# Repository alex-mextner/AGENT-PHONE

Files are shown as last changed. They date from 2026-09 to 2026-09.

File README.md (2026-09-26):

# AGENT-PHONE

**AGENT** is a wrist-worn personal computer built around a wide landscape display, [Agent OS](https://agentos-bible.vercel.app/), and keyboardless interaction. It is intentionally neither a miniature phone nor a conventional smartwatch. **AGENT-PHONE** is the public hardware repository name.

Working naming:
- **AGENT** — product / hardware family;
- **[Passport / Sapio State](https://github.com/alex-mextner/sapio-state)** — portable identity and residency research related to the device;
- **Screen** — descriptive name for the primary wrist display;
- **[Telekinesis](docs/input-research.md)** — multimodal screen-off input system;
- **[Agent Ring](docs/ring-and-spatial-input.md)** — tactile and spatial input accessory;
- **[Agent Camera](docs/camera-strategy.md)** — detachable photography module;
- **Agent Glasses** — optional gaze, spatial-context, and low-duty-cycle display accessory described across the companion-device research.

The product explores a simple premise: a personal computer should not need to occupy a hand, pocket or bag. AGENT stays on the wrist, keeps its display dark whenever possible, and hands heavy visual work to a nearby TV, monitor or optional glasses display.

## Product thesis

- One uninterrupted wide landscape OLED, visually around two Apple Watch Ultra faces side by side.
- Nearly borderless left/right edges.
- A very thin hidden tilt carrier so the wrist can rest naturally while the display faces the user.
- A detachable compute/display module with only a short-duration reserve battery.
- Most battery mass lives in the cuff/base and two curved battery plates integrated into the sides of the open cuff.
- An optional **external endurance battery** can move much more energy to the torso (underarm or lower back) through a flat clothing-integrated cable.
- Base model uses a wraparound cuff rather than a conventional buckle; Dive variant can use a secure clasp.
- No rigid battery brick under the wrist.
- eSIM only; no physical SIM.
- No games by design. Video and long-form visual work should prefer a larger nearby display.
- Optional glasses provide gaze, spatial context and a low-duty-cycle display; paired bone-conduction/private audio can read results back without lighting the wrist.
- Optional ring(s) provide tactile, spatial and eyes-free controls.
- A detachable camera tile handles deliberate photography better than pointing the whole wrist at a subject.
- Nearby displays are first-class outputs: TV/monitor, glasses and **car HUD** can receive the current navigation, media or task context instead of forcing it onto the wrist.

## Telekinesis input

**[Telekinesis](docs/input-research.md)** combines wrist sEMG, IMU, optical sensing, deliberate silent articulation, gaze, ring gestures and voice dictation.

The goal is not "mind reading." Silent speech is an intentional input mode. The system learns each user's deliberate subvocal articulation and only records it while the input mode is explicitly armed.

Screen-off composition is a core power and attention feature: the OLED can remain black while subtle haptics indicate input state, and private TTS can read the draft back for correction.

## Agent OS

AGENT is hardware for [Agent OS](https://agentos-bible.vercel.app/) ([source](https://github.com/alex-mextner/AgentOS)), an app-last, local-first, agent-native operating-system project.

Instead of shrinking phone apps onto a small display, AGENT presents task- and entity-specific views: a person, event, product, room, delivery, research task or photo can become the current interface.

See [AGENT hardware × Agent OS](docs/agent-os.md).

## Research and engineering documents

- [Product specification](SPEC.md)
- [Hardware architecture](docs/hardware-architecture.md)
- [Prototype BOM and sourcing](docs/bom.md)
- [Product and distribution strategy](docs/product-strategy.md)
- [Critical phone-failure scenarios](docs/critical-scenarios.md)
- [Deep research: keyboardless input](docs/input-research.md)
- [Ring and spatial input](docs/ring-and-spatial-input.md)
- [Camera strategy](docs/camera-strategy.md)
- [Display, silicon and connectivity](docs/display-and-connectivity.md)
- [Agent OS integration](docs/agent-os.md)
- [Visual references and design lessons](docs/references.md)
- [Naming notes](docs/naming.md)
- [Blender render pipeline](blender/README.md)

## Prototype strategy

The first physical builds deliberately separate ergonomic proof from full electronics.

1. **P0 ergonomic cuff** — PETG/TPU, real long OLED, batteries/weights in correct places, compact tilt/detach mechanism.
2. **P0 Telekinesis** — wrist sEMG/IMU + screen-off state machine, compute may remain off-body.
3. **P0 ring** — BLE/IMU/capacitive/squeeze DIY ring.
4. **P1 functional wrist** — embedded Linux/Agent OS services, camera tile, real power domains.
5. **P2 custom electronics** — wearable SoC, custom PCB/FPC, curved batteries and production-intent display.

This keeps an oversized development board from dictating the industrial design.

## Distribution hypothesis

The base AGENT device is intended to be distributed free to a limited waitlist/residency cohort. Revenue is explored through optional extensions, specialist accessories, commercial integrations and services rather than mandatory hardware margin.

This is a product hypothesis, not a finalized business model.

## Concept status

This repository is a research and industrial-design prototype. Dimensions, battery capacity, sensing accuracy, pricing and supplier availability are engineering targets or snapshots, not production claims.

## Concept renders

The [concept-render gallery](renders/) shows the device on-wrist, its tilt/detach mechanics, and representative interfaces. Current written specs remain the authority for dimensions and behavior while the physical prototype evolves.

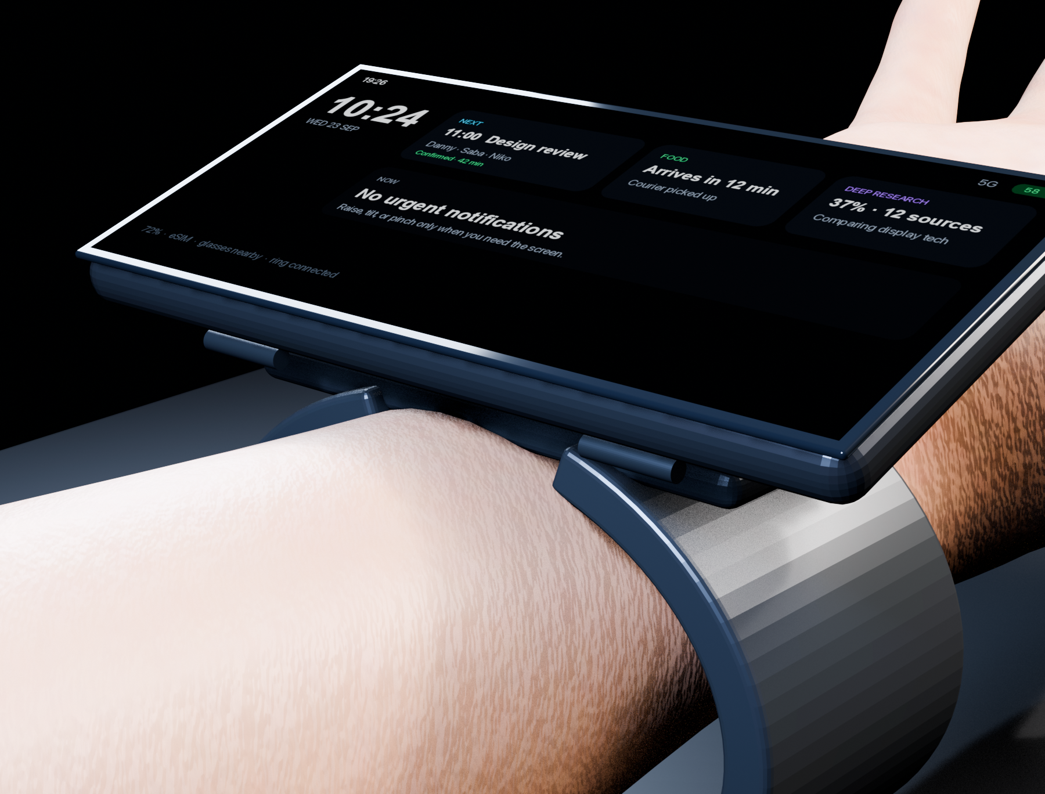
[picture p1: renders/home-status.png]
AGENT-PHONE home/status on wrist


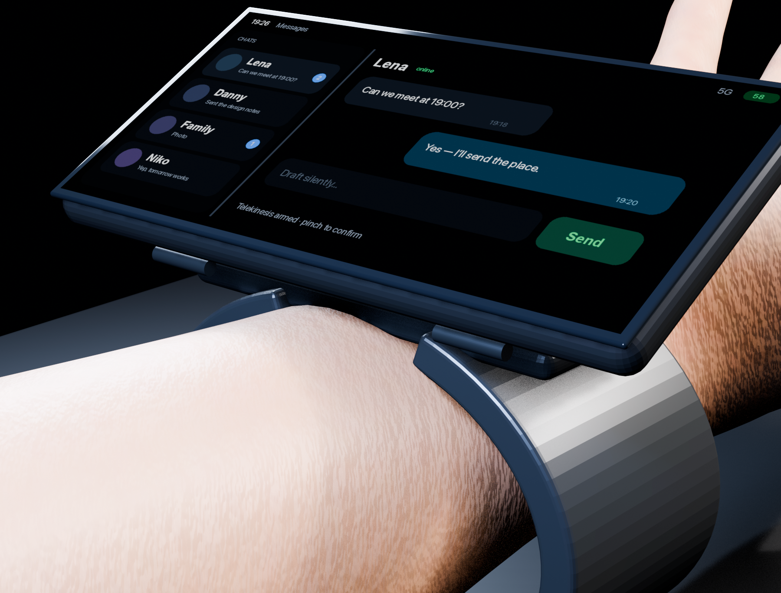
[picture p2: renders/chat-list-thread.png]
AGENT-PHONE chat list + thread


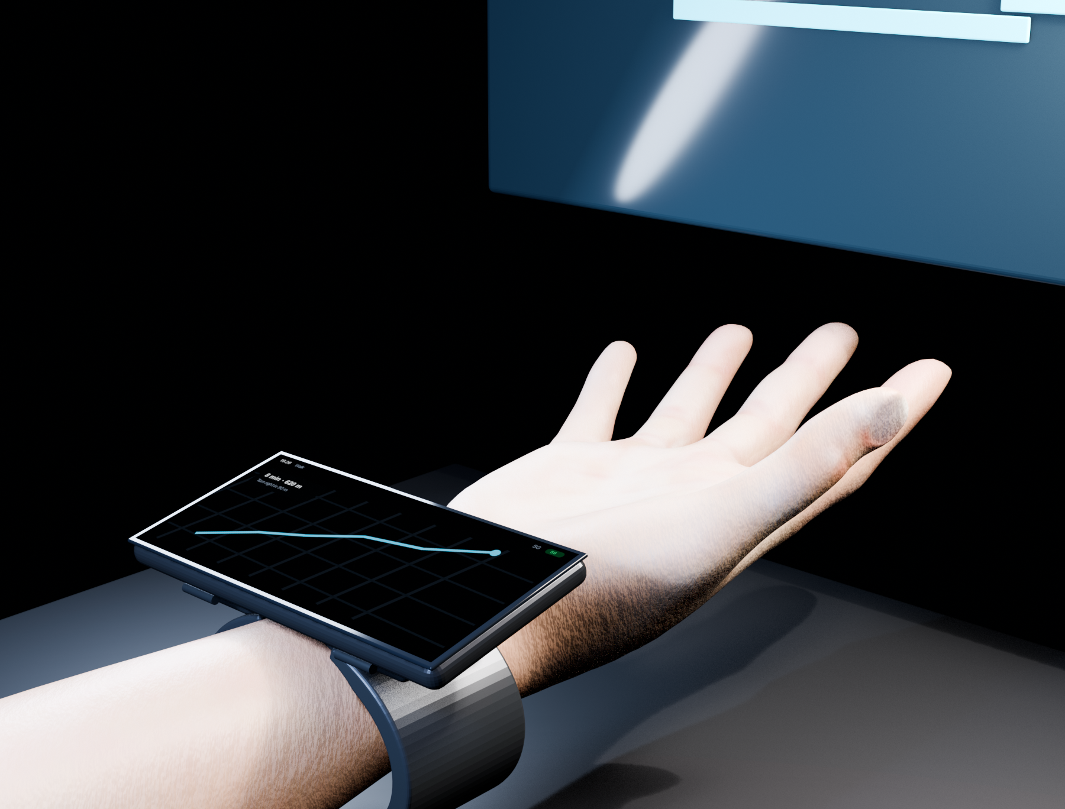
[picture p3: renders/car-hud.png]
AGENT-PHONE car HUD handoff


See [the full render set](renders/README.md).

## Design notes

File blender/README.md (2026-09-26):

# Render pipeline

Requires Blender 5.x and Python 3 with Pillow for UI texture generation.

## Generate UI textures

```bash
python3 blender/generate_ui.py
```

## Fetch the licensed human asset

```bash
python3 blender/fetch_human_asset.py
```

MakeHuman graphical assets are cached under `assets/human/cache/` and are not committed. Source/license details live in `assets/human/README.md`.

## Render concept views

```bash
/Applications/Blender.app/Contents/MacOS/Blender --background --python blender/screen_concept.py
```

Use `-- --scene car-hud`, `-- --scene ring-spatial`, or another scene name for one render. Add `-- --preview` for the lower-resolution preview path.

The current source checkpoint is `renders/agent-phone-concept.blend`.

## Design intent encoded by the model

- 94 × 45 mm module: approximately two Watch Ultra-sized faces side by side;
- long display axis **across the wrist**;
- edge-to-edge glass with a subordinate structural rim;
- two curved battery plates integrated into the open cuff;
- rigid cuff stops before the underside desk-contact zone;
- recessed tilt mechanism with 0° / 30° / 55° validation states;
- detachable display/compute module with a small reserve cell;
- licensed MakeHuman wrist/hand asset for lifestyle scenes;
- companion contexts for TV handoff, ring, glasses/private audio, camera tile, external battery, Dive clasp, desk/laptop and car HUD;
- every public UI state is rendered on the worn device.

This remains an industrial-design massing model, not production CAD.

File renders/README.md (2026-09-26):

# Concept renders

These images document the current AGENT-PHONE industrial-design and interaction concept. Implementation details for generating them live in [`blender/`](../blender/README.md).

## Scale and mechanics

| View | What it proves |
| --- | --- |
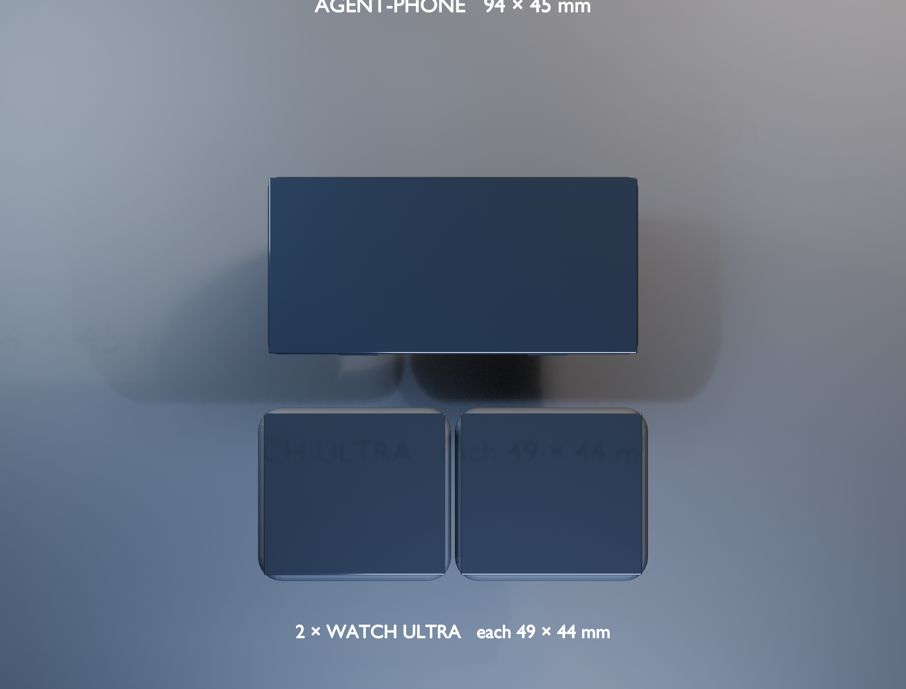
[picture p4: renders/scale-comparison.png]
Scale comparison
|  | 94 × 45 mm AGENT-PHONE compared directly with two 49 × 44 mm Watch Ultra-sized references |
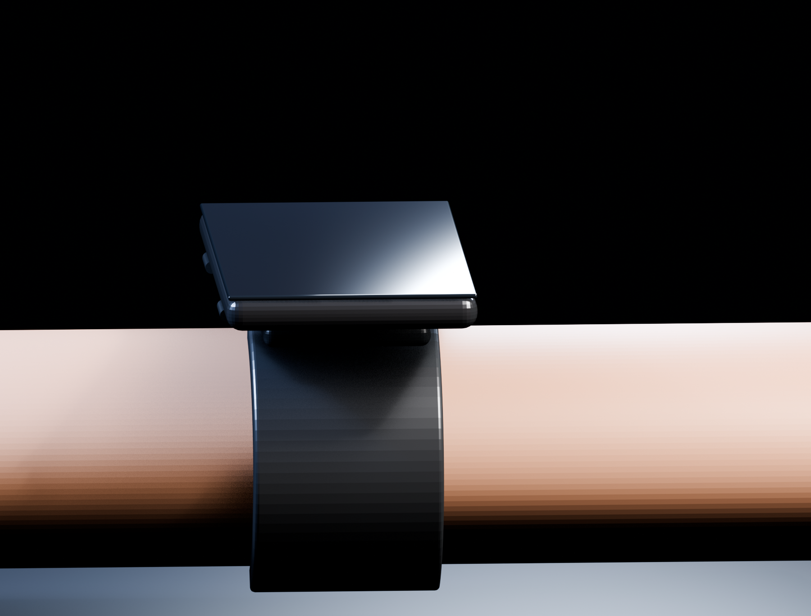
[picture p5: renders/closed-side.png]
Closed side
|  | closed thin module over the open cuff |
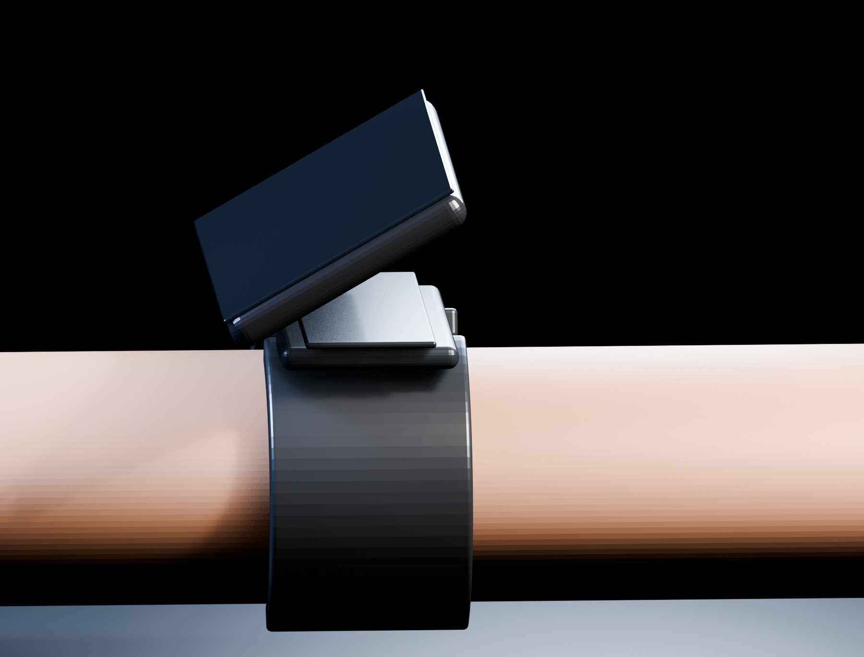
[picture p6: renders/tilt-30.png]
Tilt 30
|  | first comfortable reading angle while the arm rests |
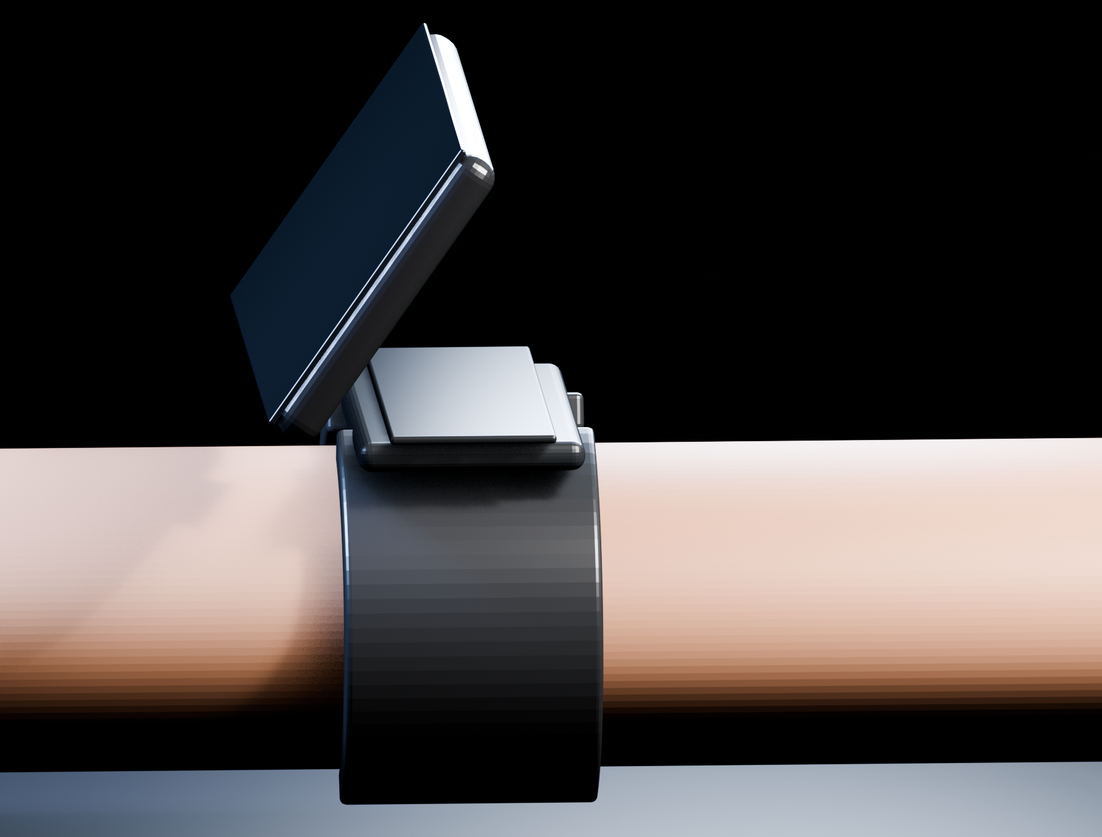
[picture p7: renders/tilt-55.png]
Tilt 55
|  | high tilt with the hinge still recessed |
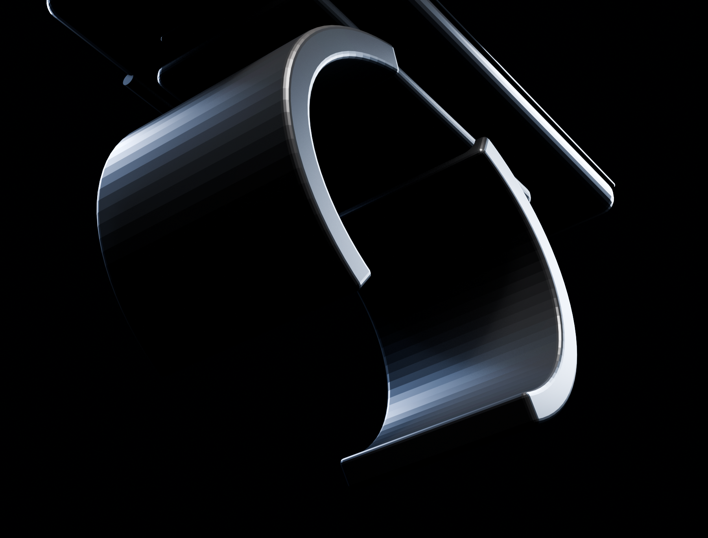
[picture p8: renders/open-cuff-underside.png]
Open cuff underside
|  | rigid battery plates stop before the desk-contact underside of the wrist |
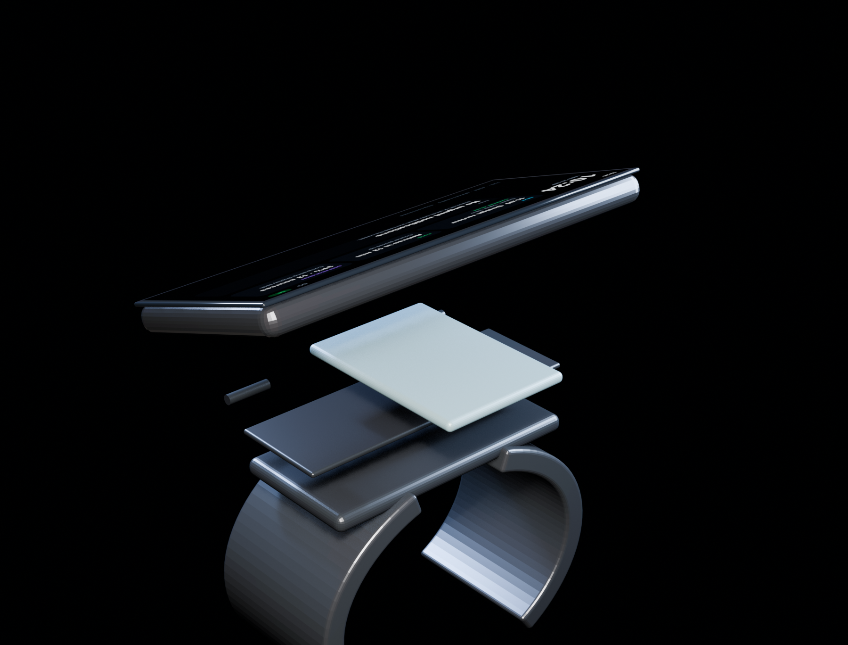
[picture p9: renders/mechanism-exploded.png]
Exploded mechanism
|  | display/compute module, thin carrier, reserve cell, contacts and cuff separated |
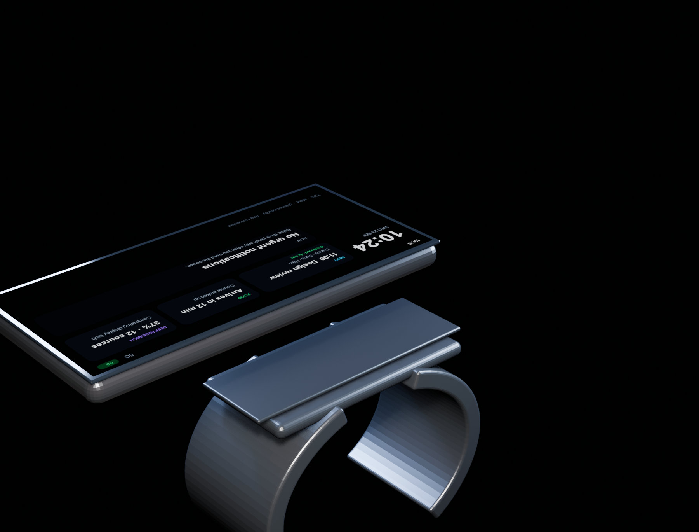
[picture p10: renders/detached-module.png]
Detached module
|  | removable display/compute module remains a coherent thin object |

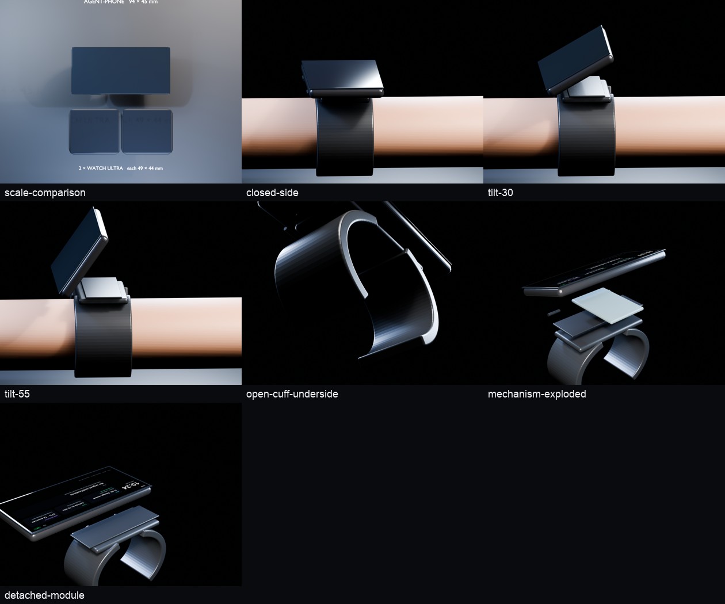
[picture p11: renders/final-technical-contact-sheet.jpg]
Technical contact sheet


## On-wrist scenarios

| View | Scenario |
| --- | --- |
| Home/status | next calendar event, food delivery and long-running AI research |
| Chat | chat list on the left, active thread on the right |
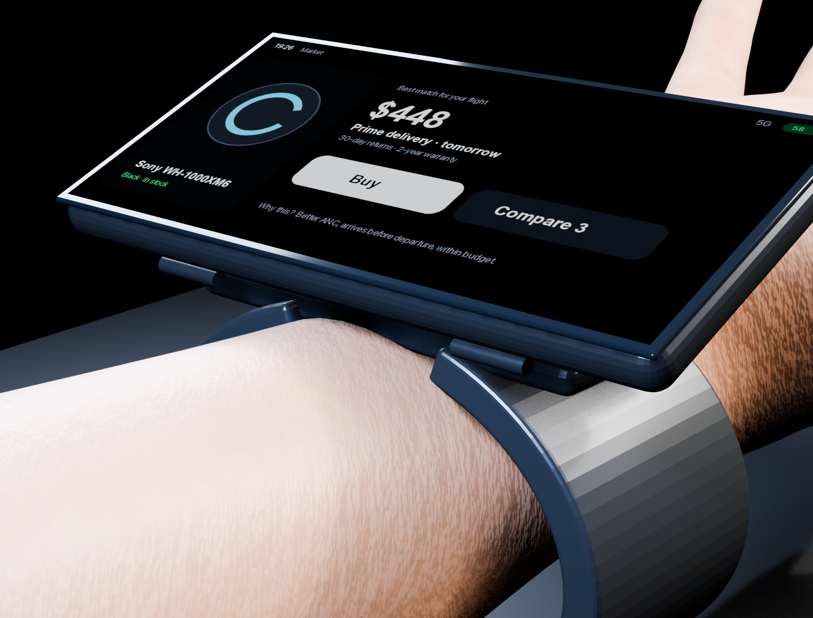
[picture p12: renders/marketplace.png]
Marketplace
|  | product decision and purchase without a phone-sized portrait app |
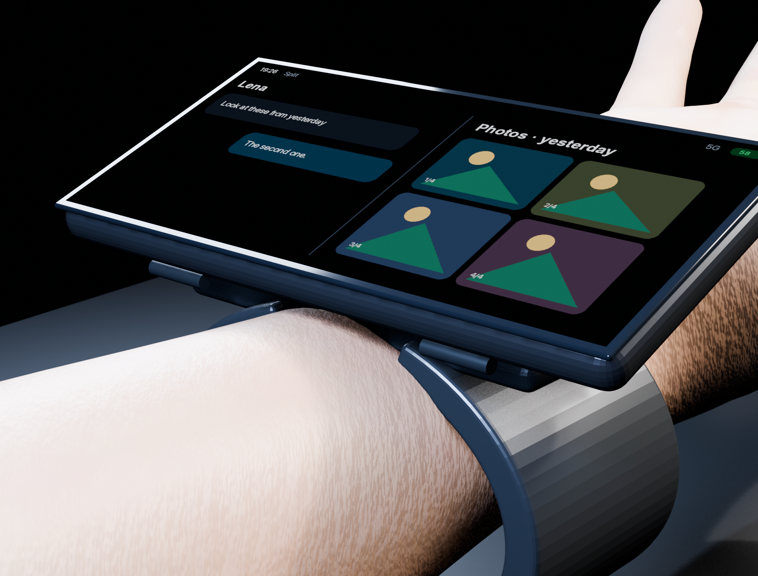
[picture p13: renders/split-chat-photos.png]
Split
|  | chat + photos on one wide surface |
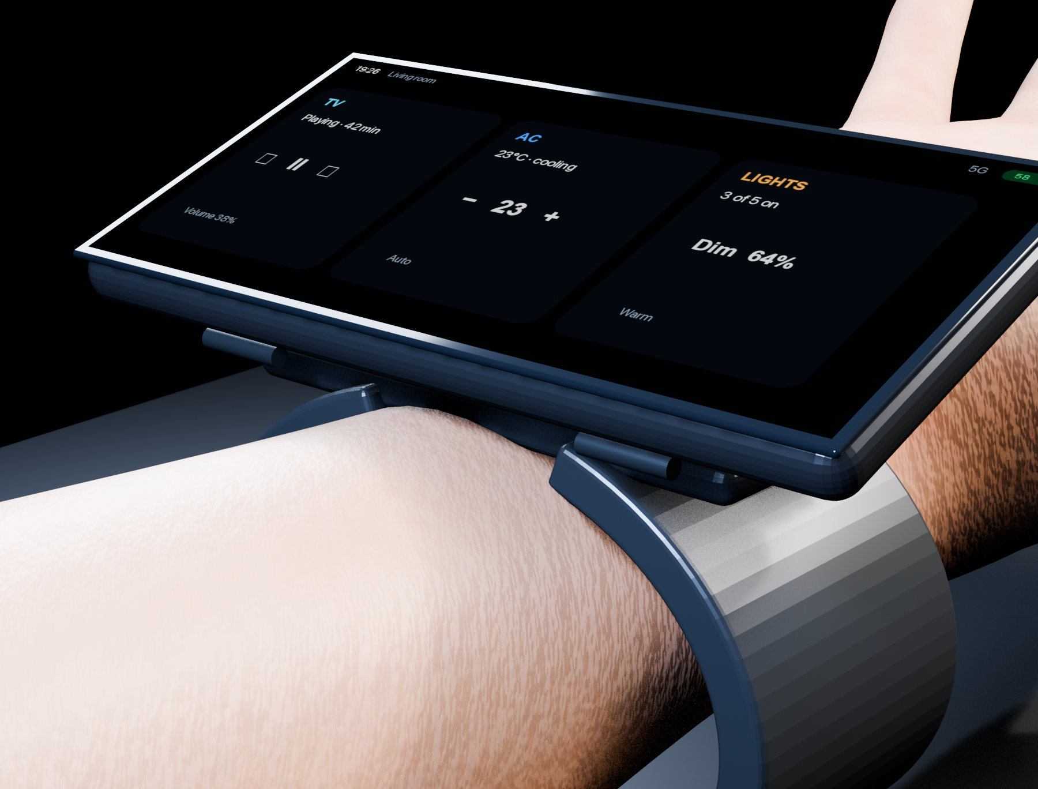
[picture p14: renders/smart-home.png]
Smart home
|  | TV / AC / lighting control |
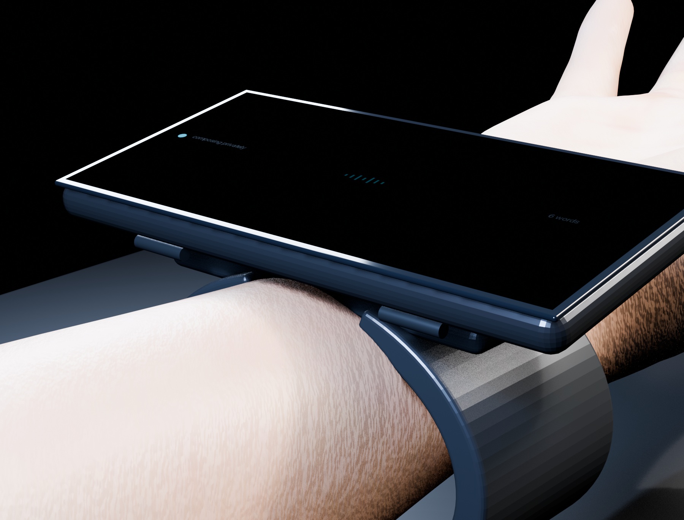
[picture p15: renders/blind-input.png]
Blind input
|  | almost-black screen during private Telekinesis composition |
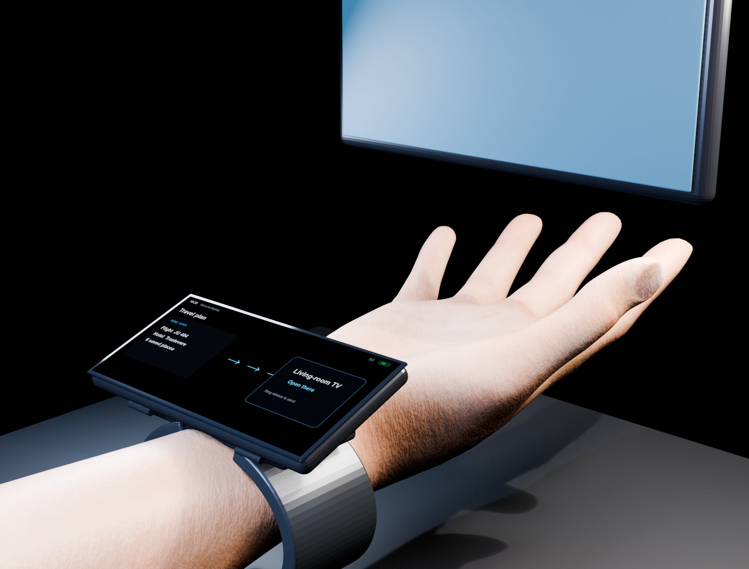
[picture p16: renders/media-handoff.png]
Media handoff
|  | move the current entity to a nearby TV |
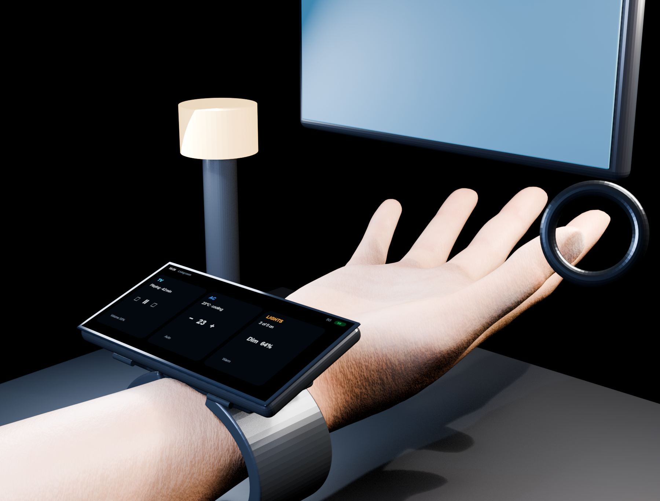
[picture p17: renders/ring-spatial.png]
Ring spatial
|  | ring + room context for spatial device control |
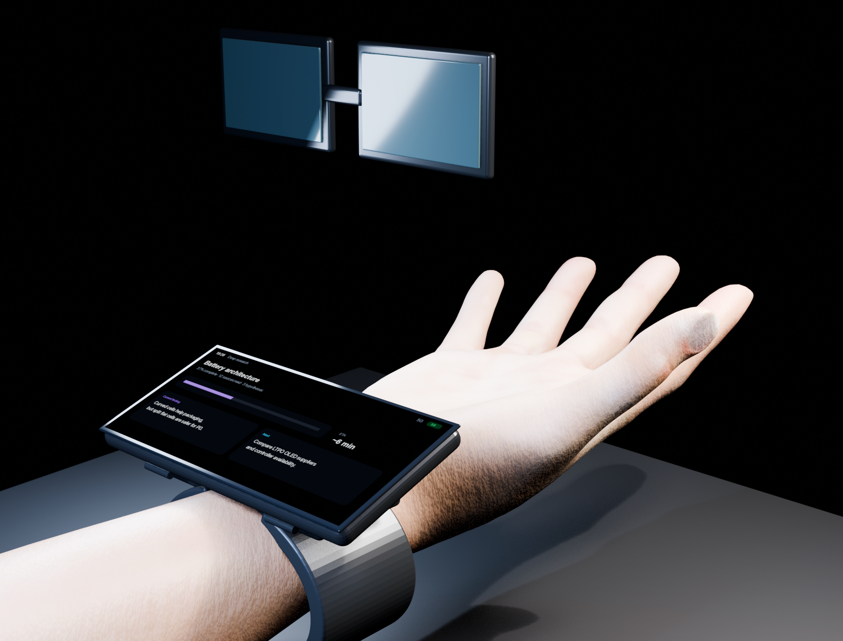
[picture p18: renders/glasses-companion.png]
Glasses companion
|  | glasses, gaze/spatial context and private audio companion |
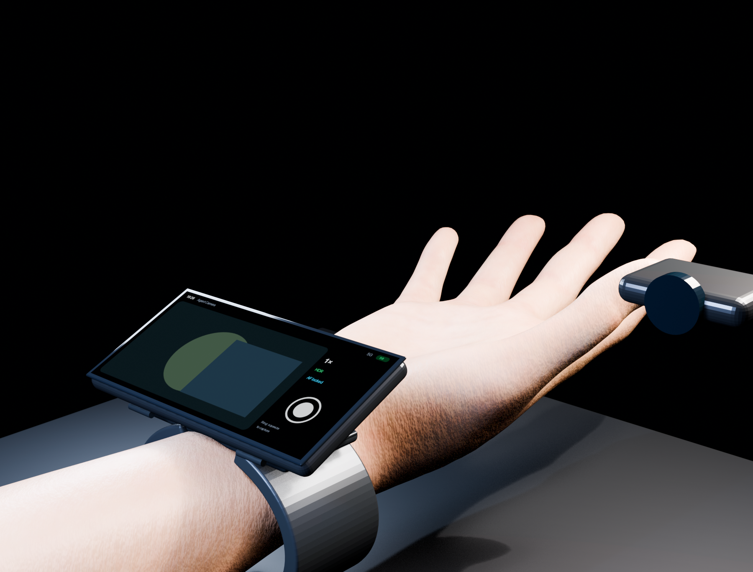
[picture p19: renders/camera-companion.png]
Camera companion
|  | detachable camera tile with the wrist as controller/viewfinder |
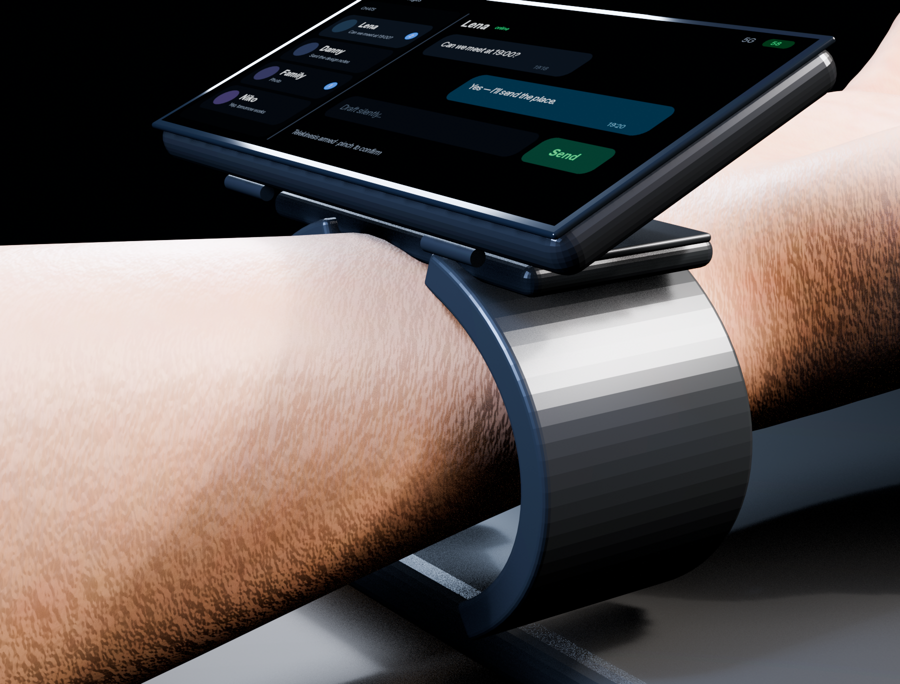
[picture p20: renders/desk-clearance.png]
Desk clearance
|  | open cuff leaves the underside usable against a desk/laptop |
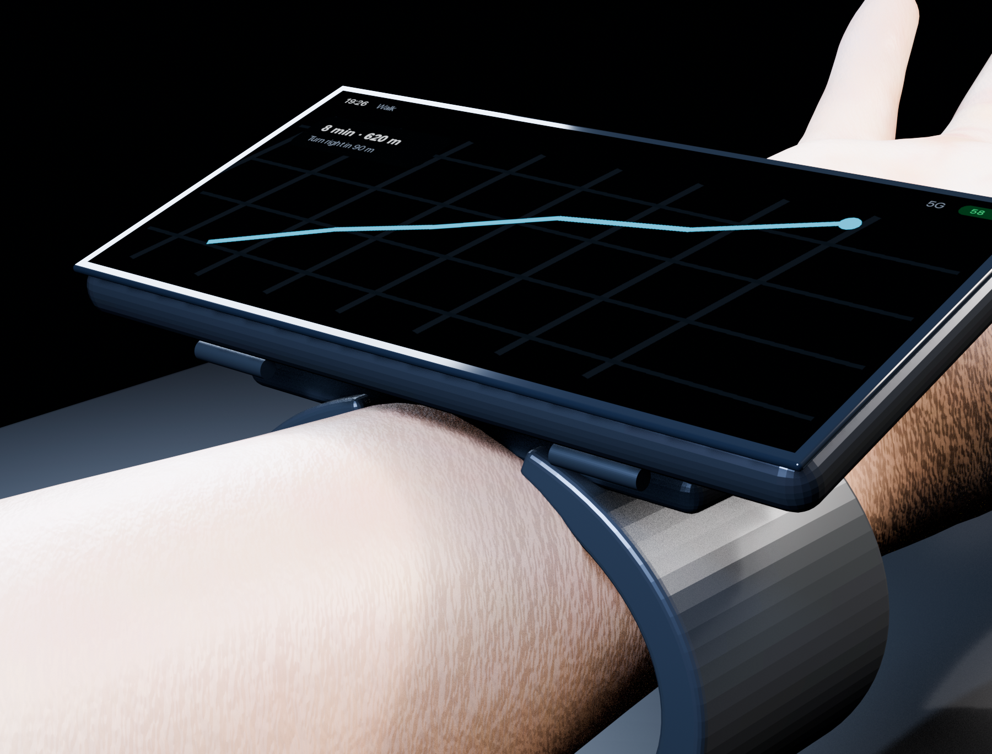
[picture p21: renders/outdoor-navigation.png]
Outdoor navigation
|  | quick glance navigation |
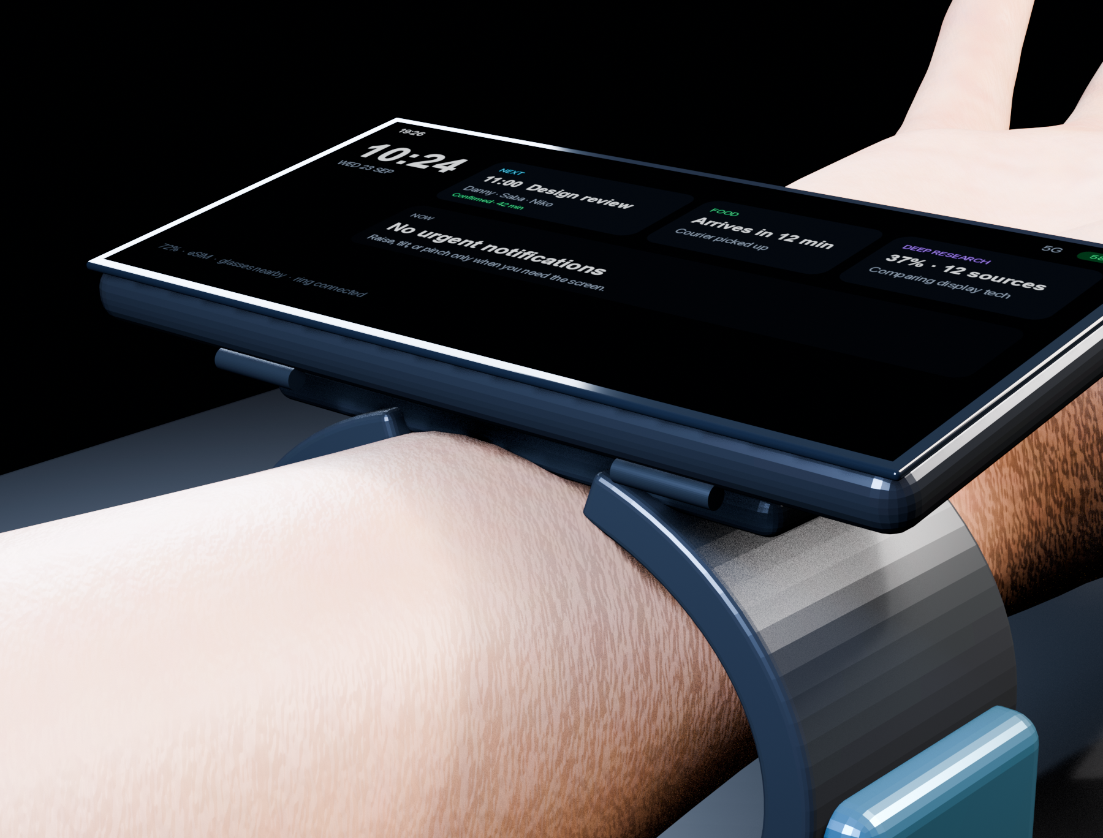
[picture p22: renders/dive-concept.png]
Dive concept
|  | secure-clasp variant for water use |
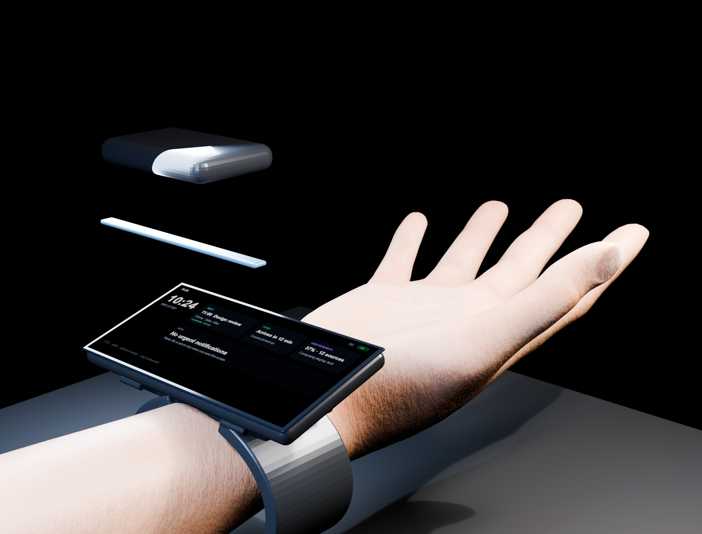
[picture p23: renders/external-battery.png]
External battery
|  | optional endurance pack + flat power ribbon; torso placement is documented separately |
| Car HUD | navigation handed off to a sparse vehicle HUD while the wrist remains the personal controller |

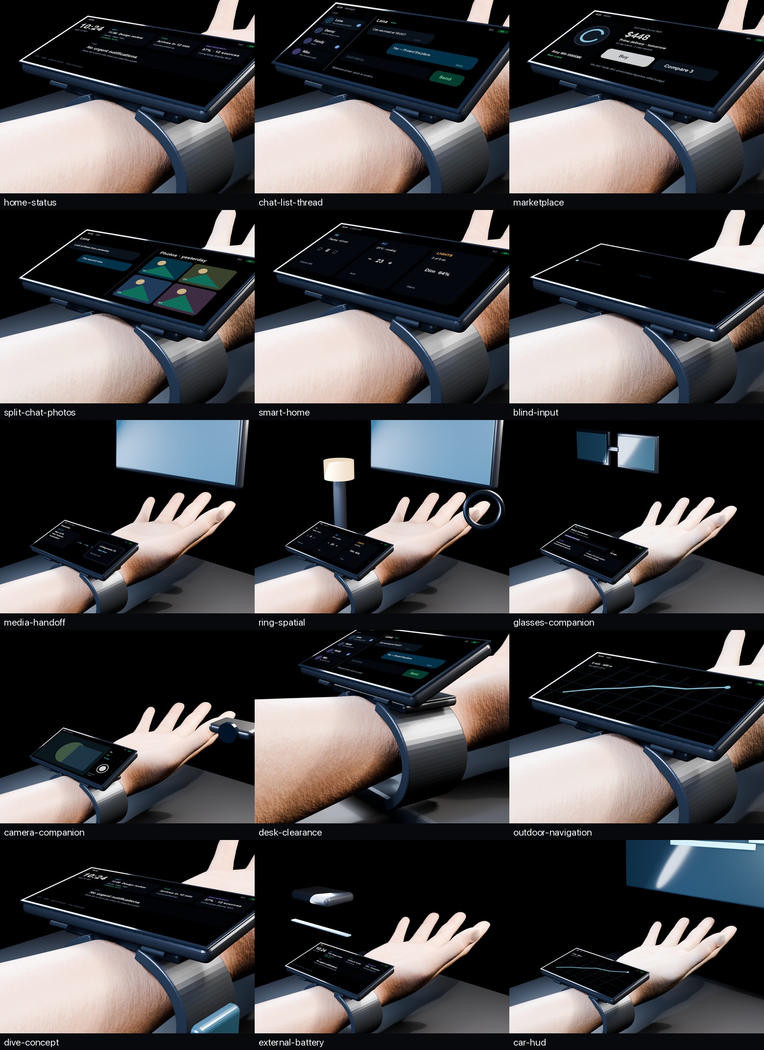
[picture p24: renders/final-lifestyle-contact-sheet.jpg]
Lifestyle contact sheet


The inspectable Blender checkpoint is [`agent-phone-concept.blend`](agent-phone-concept.blend). See [`QA.md`](QA.md) for the final render review checklist.

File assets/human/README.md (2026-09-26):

# Human wrist asset

Final on-wrist renders use MakeHuman core assets rather than the old cylinder-and-sphere validation arm.

## Source and license

- Project: [MakeHuman](https://github.com/makehumancommunity/makehuman)
- Base mesh: MakeHuman core `base.obj`
- Natural skin assets: MakeHuman system-assets pack
- License: **CC0 1.0 Universal** for the bundled graphical assets, including the base mesh, targets, skins, poses and expressions
- License statement: https://github.com/makehumancommunity/makehuman/blob/master/LICENSE.md
- System-assets pack: https://static.makehumancommunity.org/assets/assetpacks/makehuman_system_assets.html

MakeHuman's application source has a different software license; this project uses only the CC0 graphical assets.

## Cache policy

Large source assets are **download-on-demand** and are not committed to this repository.

Expected local cache:

```
assets/human/cache/base.obj
assets/human/cache/makehuman_system_assets_cc0.zip
assets/human/cache/system-assets/...
```

Run:

```bash
python3 blender/fetch_human_asset.py
```

The final rendered PNGs may be committed. The generated Blender checkpoint may contain a derived CC0 wrist mesh so the scene remains inspectable.

## Why this source

The previous render used primitive cylinders/spheres and looked like a mannequin. The MakeHuman base mesh provides real hand/finger/wrist topology and can use the project's natural-skin textures while remaining legally reproducible.

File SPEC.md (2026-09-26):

# AGENT — Product Specification

Status: concept / feasibility prototype
Working product name: **AGENT**
Working identity-layer name: **Passport**
Working input-system name: **Telekinesis**

## 1. Problem

A phone occupies a hand, pocket or bag, is easy to misplace, pulls on one side of clothing, and defaults most software to a narrow portrait viewport. AGENT is intended to make common communication, AI, navigation, purchasing and control tasks available without carrying a phone-shaped object.

It is deliberately not a replacement for every screen. Video and long-form visual work are better on a TV, monitor, tablet or glasses. Games are intentionally excluded from the core device.

## 2. Industrial design

### 2.1 Display module

Prototype envelope:
- outer module target: about **94 × 45 × 6.2 mm**;
- active display target: about **91 × 42 mm**, close to two Apple Watch Ultra cases joined into one uninterrupted surface;
- the **long display axis runs across the wrist**, approximately like two Apple Watch Ultra cases side by side; this explicitly rotates the old Blender concept by 90°;
- the short axis follows the forearm/strap direction; UI remains a landscape workspace when the display tilts toward the face;
- visible structural border stays under the edge-to-edge glass at roughly 0.7–1.5 mm;
- rounded corners and no visual split between "two watches."

The display module contains the primary SoC, RAM/storage, eSIM radio path, antennas that cannot live in the base, microphones, wireless radios, haptics/audio interfaces, and a small reserve cell.

### 2.2 Base and battery wings

The base remains on the wrist. It holds the main battery, power management, wrist sensors, the haptic actuator, and the mechanical carrier for the detachable module.

The main batteries live in two curved cuff plates that descend around the **left and right sides of the wrist** from the central base. They follow the wrist circumference, remain physically continuous with the base, and stop before the underside desk-contact zone. They must never read as detached battery bars.

The base model is an **open bracelet/cuff** rather than a conventional watch strap with a buckle. A Dive variant may use a secure buckle/ratchet for wetsuit use.

There is no rigid battery pack or clasp at the underside of the wrist, because that surface contacts a desk, keyboard and laptop.

### 2.3 Hidden tilt mechanism

The hinge must visually disappear when closed. The first prototype uses a thin carrier plate that stays with the base:
- two short friction pivots, approximately 2.2–3.0 mm diameter, recessed below one **short edge** of the module;
- hinge axis runs **across the wrist**, parallel to the display's long axis;
- closed, ~30° and ~55° positions;
- a hard mechanical stop before ~70°;
- no large central barrel or exposed camera-style hinge.

The detachable screen docks to the tilting carrier with magnets plus a positive latch. Spring contacts provide power/data. A short slide-and-lift motion prevents accidental vertical release.

Separating "tilt" from "detach" keeps the screen module thin and lets the carrier take mechanical loads.

### 2.4 Battery allocation

Prototype target, assuming ~3.85 V nominal Li-ion chemistry:
- detachable module: ~100–180 mAh (~0.4–0.7 Wh), sized for at least a short 10-minute standalone interaction;
- base + curved wings: ~2,100–3,000 mAh (~8–12 Wh) depending wrist size and thickness;
- stretch target around 3,200 mAh only if comfort tests permit.

Capacity is a packaging target, not a promise. Wh, discharge curve, radio duty cycle and display behavior matter more than mAh alone.

For the first physical prototype, use conventional high-energy-density Li-ion/Li-poly pouch cells in segmented curved compartments. Treat solid-state and exotic structural batteries as research tracks until suppliers offer validated cycle life, safety and form factors.

## 3. Screen behavior

The display is normally dark. Always-on information uses only a few emissive pixels where useful.

Home / lock state should show:
- current time, compactly;
- next calendar event and whether it is confirmed;
- food-delivery ETA/status;
- status of long-running AI work such as deep research;
- only urgent notifications, not a feed.

Primary visual tasks:
- marketplace browse and purchase;
- Telegram-like messaging;
- split view: chat + photos;
- TV / air-conditioner / lighting control;
- maps and short navigation;
- AI assistant status and results;
- quick document/credential views.

Video should offer "play here" only as an exception and otherwise suggest the nearest trusted TV/display. Navigation and driving-relevant state may hand off to a compatible car HUD; non-driving notifications should be suppressed while driving. Games are intentionally absent.

## 4. Screen-off composition

Telekinesis composition is designed to work with the display off:
1. User arms input with a deliberate gesture.
2. A tiny pixel indicator and one haptic pulse confirm capture.
3. Silent articulation, finger gestures or dictation enter text.
4. Word/phrase boundaries receive subtle haptic confirmation.
5. Low-confidence segments produce a distinct haptic pattern.
6. TTS or bone-conduction readback can speak the draft privately.
7. The user corrects with gesture, silent speech or voice.
8. Send is a separate deliberate action.

The system must never infer that ordinary private thoughts are input.

## 5. Multimodal controls

Required gesture vocabulary:
- thumb–index tap and double tap;
- pinch / squeeze;
- thumb rubbing or sliding against index finger;
- wrist flick away-and-back;
- wrist roll / pronation and return;
- wrist flex inward and return;
- finger chords recognized by sEMG;
- ring tap / double tap / squeeze / capacitive slide;
- ring "virtual rotation" by pinching and moving around its touch arc;
- gaze target + pinch when compatible glasses are present;
- point + confirm for room/device control;
- deliberate grab/move/release for cross-device object transfer.

Sensor fusion should combine sEMG, IMU, PPG, ring motion, optional UWB and glasses vision/contextual confidence rather than assigning every gesture to a single sensor. Spatial gestures are mode-gated so ordinary hand motion cannot trigger effects.

## 6. Companion devices

Optional companion nodes:
- **Agent Ring** with IMU, tactile/capacitive input, squeeze sensing and optional UWB/health sensing;
- glasses with a low-duty-cycle display, **gaze**/eye tracking and camera-based spatial context;
- earbuds/headphones or temple audio for private TTS and **bone-conduction**/air audio;
- glasses/earbuds/neck wearables as an R&D path for deliberate **silent articulation** and tongue/jaw sensing using acoustic, ultrasonic, optical, EMG, PPG or strain signals;
- necklace/choker for optical PPG, strain or throat sensing;
- pendant as a microphone/compute/radio accessory;
- detachable camera tile for deliberate photography;
- optional external endurance battery worn at the **underarm**, **lower back** / sacrum, or another low-interference torso position, connected with a flat clothing-integrated cable;
- nearby trusted displays including TV/monitor and **car HUD**.

AGENT remains independently usable without these accessories. Silent-articulation sensing is deliberate, personalized input; the system must not claim passive thought reading.

## 7. Camera model

The wrist is not the primary photography position.

- Glasses camera: spatial context, hand tracking, QR/label scan and first-person capture.
- Detachable camera tile: deliberate photography, autofocus/HDR, clothing clip or handheld framing.
- Wrist camera: optional utility/context sensor only.
- Ring can act as focus/shutter/zoom/exposure control.
- Wrist display, glasses or another trusted screen can become the viewfinder.

See [Camera strategy](docs/camera-strategy.md).

## 8. Connectivity

- eSIM only.
- 5G RedCap-class cellular preferred for lower complexity/power than full smartphone 5G.
- Wi-Fi, Bluetooth and UWB for display handoff, accessories and proximity.
- GNSS may be integrated or delegated opportunistically.
- NFC should be considered for access/payment, subject to certification and secure-element architecture.
- A tiny always-on domain handles low-rate connectivity/notification triage while the application SoC sleeps.

## 9. Agent OS

AGENT is a hardware endpoint for [Agent OS](https://agentos-bible.vercel.app/). The UI should be entity/task-first rather than a grid of miniature phone apps. Ring, gaze and Telekinesis inputs publish typed intents/events into the capability system rather than injecting unrestricted key events.

See [AGENT hardware × Agent OS](docs/agent-os.md).

## 10. Privacy and safety

- Silent-speech capture is opt-in and visibly/haptically armed.
- Prefer local feature extraction and local inference for raw biosignals.
- Raw EMG/PPG/audio retention defaults to off.
- Personalized adaptation must be inspectable and resettable.
- Glasses cameras and microphones are not prerequisites for core operation.
- Authentication-sensitive actions require a second confirmation channel or explicit gesture.

## 11. Prototype acceptance tests

A prototype is useful only if it proves ergonomics:
- wrist can rest on a laptop palm rest and desk with no rigid underside obstruction;
- tilted screen is readable while forearm rests naturally;
- one-handed tilt/close/detach works without looking at the mechanism;
- closed hinge does not visually dominate the product;
- screen module cannot release from a knock;
- battery wings do not collide with wrist bones across a test set of wrist sizes;
- all UI demo states are shown on an actual wrist render.

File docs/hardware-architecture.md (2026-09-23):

# Hardware architecture

Updated: 2026-09-23

## Principle: never cold-boot for an interaction

AGENT should feel instantly awake because the application processor normally **suspends**, rather than shutting down. A tiny always-on domain remains active for radios, gestures, sensors, haptics and wake decisions.

The architecture is intentionally asymmetric:

- **Always-on controller**: notifications, gesture classifier, ring/glasses links, low-rate sensor fusion, haptics, wake policy.
- **Application SoC**: UI composition, browser/media codecs, larger local models, camera processing and rich apps/micro-apps; normally asleep.
- **Cellular**: low-power signaling must not require waking the application SoC.
- **Display**: stays black unless the interaction actually benefits from pixels.

This is more realistic than rebooting a RAM-only OS for every interaction. Suspend-to-RAM plus persistent local state gives the instant-on behavior the product needs.

## Final-product compute target

Qualcomm Snapdragon Wear Elite is the closest currently announced reference architecture:
- 3 nm process;
- dedicated NPU up to 12 TOPS;
- support for up to 2B-parameter on-device models;
- 5G RedCap, Micro-Power Wi-Fi, Bluetooth 6, UWB, GNSS and NB-NTN;
- "Intelligent Low-Power Islands";
- eMMC support up to 64 GB.

Official:
https://www.qualcomm.com/wearables/products/snapdragon-wear-elite-platform

This does not mean the product is locked to Qualcomm. The important properties are the heterogeneous low-power islands, wearable thermal envelope, integrated connectivity and hardware video/AI blocks.

## Always-on companion

### Product architecture

Use a tiny MCU / low-power island for:
- packet and notification triage;
- ring and accessory BLE;
- wrist/ring IMU fusion;
- simple sEMG/gesture classifier;
- haptic feedback;
- sparse display status;
- wake-word / event detection where appropriate;
- secure wake of the application SoC.

A notification classifier does not need an LLM. Start with rules plus a tiny quantized classifier. It should decide things such as:
- ignore until later;
- haptic only;
- show one-line status;
- wake application SoC;
- urgent call/alarm.

### Cellular research option: nRF9161

Nordic nRF9161 combines an Arm Cortex-M33 application core with LTE-M/NB-IoT and GNSS, 1 MB flash and 256 KB RAM.

https://www.nordicsemi.com/Products/nRF9161
https://www.digikey.com/en/products/detail/nordic-semiconductor-asa/NRF9161-LACA-R/22107874

It is a good prototype for **low-power notification/data connectivity**, not a substitute for smartphone-class broadband. LTE-M/NB-IoT is intentionally constrained.

For early AGENT prototypes, the cleanest sequence is:
1. Wi-Fi/BLE tether for rich data;
2. nRF91-class cellular for always-on messaging experiments;
3. 5G RedCap wearable platform for the integrated product.

## Two compute rails

### Rail A — always on

Typical state:
- MCU active intermittently;
- BLE connected;
- cellular paging / low-rate data;
- IMU interrupt mode;
- sEMG only while armed or sampled at a low duty cycle;
- OLED entirely off or only a few pixels active.

### Rail B — application

Wake on:
- display raise/tilt;
- explicit ring/sEMG command;
- call;
- camera capture;
- AI request requiring local compute;
- rich UI handoff.

The app processor should return to suspend immediately after the interaction rather than waiting for a phone-style screen timeout.

## Prototype compute choices

### P0: laptop/phone off-body

For validating industrial design and input, the first wrist prototype should not carry a Linux SBC at all. A small BLE MCU in the cuff streams input to a nearby computer. This keeps the prototype thin enough to test the actual ergonomics.

### P1: Milk-V Duo S-class board

An inexpensive embedded Linux/RTOS board can validate local services, UI protocol and wake domains, but its square development-board shape does not represent final packaging.

Official:
https://milkv.io/duo-s

### P1 alternative: Raspberry Pi Zero 2 W

Useful for camera/UI integration and cheap enough to treat as disposable prototype hardware. It is 65 × 30 mm and should live in an oversized engineering cuff, not be mistaken for final packaging.

https://www.raspberrypi.com/products/raspberry-pi-zero-2-w/

### Bench prototype: Compute Module 5

CM5 gives a powerful Linux environment, camera/display I/O and up to 64 GB eMMC, but at 55 × 40 × 4.7 mm it is too large and power-hungry for the final wrist computer.

https://www.raspberrypi.com/products/compute-module-5/

Use it only for bench integration and software development.

## Storage

The user's desired split — small fast system storage plus a much larger "heavy file" store — is sensible, but an M.2 NVMe SSD is the wrong final form factor.

### Product target

- **64 GB** soldered system storage for OS, local entities, models and rollback slots.
- **512 GB** optional high-density UFS / managed NAND package for media, cached datasets and local AI assets.
- Encryption keys held by the secure element / hardware-backed keystore.
- All storage treated as a local cache of user-owned objects, not an app silo.

A soldered UFS/NAND package avoids the connector, controller idle power and physical envelope of an M.2 SSD.

### Prototype

Use microSD or a tiny USB/NVMe adapter off-body during software work. Do not distort wrist industrial design to accommodate it.

## Display interface

The prototype display is likely MIPI-DSI. The application board can initially sit off-wrist if necessary, with a flexible cable into the display.

The final display controller should support:
- per-pixel emissive black;
- very low static refresh;
- self-refresh / panel RAM if supplier offers it;
- partial updates;
- display wake controlled from the always-on domain.

## Battery / power domains

Use at least three independently switchable rails:
1. always-on MCU/radios;
2. display/touch/haptics;
3. application SoC/storage/camera.

The detachable screen reserve cell only bridges:
- detachment;
- a short handheld interaction;
- graceful sleep/shutdown if it is not returned to the base.

Most energy belongs in the curved cuff/battery wings.

## Cuff construction

The base version uses a wraparound cuff rather than a conventional watch strap:
- two curved PETG shells for the first prototype;
- flexible inner liner against skin;
- split battery compartments above and below the screen;
- no rigid closure under the wrist;
- enough spring/compliance to slip over the hand or open laterally.

The **Dive** variant may use a real buckle/ratchet because security over a wetsuit matters more than desk comfort.

## No physical buttons

The prototype deliberately omits buttons.

Hard recovery should still exist through:
- hidden magnetic/reed service trigger;
- charger/dock sequence;
- capacitive service pad;
- debug pads inside the shell.

Normal interaction uses touch, ring, gestures, haptics and voice.

## Security boundary

The always-on controller must not become an ambient master key. It receives narrow capabilities:
- wake display;
- vibrate;
- read specific sensor streams;
- accept authenticated accessory packets;
- request a higher-trust agent action.

Sensitive effects remain capability-gated in Agent OS.

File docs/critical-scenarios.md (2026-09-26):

# Critical phone-failure scenarios

AGENT-PHONE is most useful where a handheld phone has the wrong physical interaction model, not merely where a smaller screen is convenient.

The matrix below is deliberately skeptical: every advantage is paired with the new risk introduced by a wrist computer, ring, glasses, audio, or body-worn battery. “Screen-off” describes the path that should remain usable while the OLED is black.

| Scenario | Why a phone fails | AGENT advantage | Screen-off path | Accessory dependency | New risk / constraint | Evidence / reference |
| --- | --- | --- | --- | --- | --- | --- |
| Industrial / frontline work | Tools, ladders, machinery, manuals and flashlights already occupy both hands. | Wrist glance + voice/silent input + ring keeps both hands on the task. | Haptic alerts, private audio, ring confirmation. | Ring or glasses helpful, not required. | Any display can still distract around machinery; actions need lockouts. | https://www.realwear.com/blog/your-most-important-tools-are-your-hands-what-is-hands-free-operation |
| Warehouse / picking / inventory | Repeatedly pulling out a phone slows scan-sort-carry loops. | Wrist computer remains present while hands pick, sort and scan. | Haptics + scanner/ring confirmation. | Scanner/ring optional. | Cuff must survive impact, cold and cleaning. | https://www.zebra.com/us/en/products/mobile-computers/wearable-computers/wt6400.html |
| Cycling / scooter navigation | Holding or typing on a phone reduces peripheral performance and increases workload. | Minimal glance navigation, haptic turns and private audio reduce head-down interaction. | Turn haptics + audio only. | Glasses/audio optional. | Must never encourage messaging while moving; HUD clutter can distract. | https://pubmed.ncbi.nlm.nih.gov/20069479/ |
| Car HUD | Phone navigation competes for a head-down glance and often sits off the forward sightline. | AGENT can hand navigation, calls and critical status to the vehicle HUD automatically while the wrist screen stays dark. | Audio + haptic confirmations; HUD only for sparse driving-relevant cues. | Compatible vehicle HUD. | HUD complexity can cause attentional tunneling; non-driving notifications must be suppressed. | https://pubmed.ncbi.nlm.nih.gov/37287261/ |
| Healthcare / clinical work | Phones are repeatedly handled around gloves, patients and shared surfaces. | Washable cuff plus voice/silent/ring input can reduce phone handling. | Haptics + private audio + silent articulation. | Ring/audio optional. | Wearable is not sterile by default and needs cleaning protocols. | https://pmc.ncbi.nlm.nih.gov/articles/PMC10552405/ |
| Cold / gloves / snow | Capacitive touch and pocket access become awkward with gloves. | Ring, sEMG, wrist motion, voice and haptics provide redundant controls. | Fully possible for short actions. | Ring improves reliability. | Sensors must distinguish deliberate gestures from cold tremor/motion. | https://support.apple.com/102567 |
| Rain / wet or dirty hands | A wet touchscreen is unreliable and the phone itself becomes another contaminated surface. | Gesture/ring/voice paths avoid touching the screen. | Haptic + audio confirmation. | None required. | Water sealing and accidental gestures need validation. | https://support.apple.com/102567 |
| Cooking / food prep | Hands are wet, oily or contaminated and a phone occupies counter space. | Timers, recipe steps, calls and appliance control stay on wrist. | Audio next-step + ring/gesture. | Audio/ring optional. | Hygiene and heat exposure require material limits. | Product hypothesis. |
| Diving / boating | A normal phone is inaccessible underwater and awkward with wet hands. | Dive cuff can become the primary status/navigation surface with haptics and physical/gesture fallbacks. | Haptics + minimal emissive status. | Dive clasp / sensors. | Waterproofing, pressure, gloves and false inputs are safety-critical. | https://www.garmin.com/en-US/p/852159 |
| Climbing / rescue / field repair | Letting go of an anchor, tool or rope to retrieve a phone is unsafe. | Wrist status + private audio + ring can keep the task hand available. | Navigation/SOS/audio/haptic. | Ring/glasses useful. | Gestures must not trigger from climbing motions; impact resistance matters. | Product hypothesis informed by hands-free industrial systems. |
| Carrying a child / groceries / luggage | One or both hands are already occupied. | Messaging, navigation, calls, access and payment remain available without retrieving anything. | Voice/silent reply + haptic confirmation. | None required. | Accidental child contact and privacy in public audio. | Product hypothesis. |
| Cane / crutch / temporary injury | A phone assumes one free dexterous hand. | Gaze, speech, ring, wrist gestures and silent articulation are redundant input channels. | Audio/haptic path can avoid touch entirely. | Depends on individual ability. | Accessibility cannot depend on one gesture vocabulary; must be configurable. | https://support.apple.com/en-us/111111 |
| Limited dexterity / limb difference | Small phone targets and two-hand workflows can be inaccessible. | Multiple sensing modalities can be personalized per user. | Haptics + audio + chosen gesture channel. | Optional ring/glasses. | Biosignal models need inclusive training and calibration. | https://support.apple.com/en-us/111111 |
| Crowded transit / theft-prone places | Taking out a large valuable phone exposes it and consumes a grip hand. | Glanceable wrist status reduces visible handheld-device time. | Haptics + private audio. | None required. | A visible wrist computer can itself attract theft; quick lock is required. | Product hypothesis. |
| Standing bus/train | One hand may be on a rail and the other carrying a bag. | Tilted wrist screen can be read without giving up balance. | Audio/haptic for simple actions. | None required. | Motion increases input noise and reading time. | Product hypothesis. |
| Night / bed / dark room | A bright phone screen lights the room and requires visual attention. | Silent composition works with almost all pixels off. | Tiny status pixels + haptic + private TTS readback. | Audio optional but valuable. | Audio can leak; haptics must be subtle. | Product hypothesis. |
| Meetings / face-to-face conversation | Pulling out a phone is visually disruptive and signals disengagement. | Brief wrist glance or silent reply can reduce visible screen time. | Silent articulation + haptic/TTS. | Audio optional. | Wearable checking can still be socially distracting. | Product hypothesis. |
| Spatial home/device control | Phone remotes require unlock → app → device → control. | Point ring/glasses at the TV, light or speaker, then manipulate directly. | Ring haptic confirms target and action. | Ring + optional glasses/UWB. | Wrong-device selection needs explicit confirmation. | See docs/ring-and-spatial-input.md |
| Cross-device content handoff | Phone share sheets force app-centric routing. | Grab/select an entity and hand it to TV, car HUD, glasses or another AGENT. | Haptic target preview + release gesture. | Target display/device. | Accidental disclosure to the wrong nearby device. | See docs/agent-os.md |
| Emergency quick actions | Unlocking and navigating apps wastes time when stressed or injured. | SOS, medical ID, navigation, door/light and calls can live in the always-on path. | Dedicated gesture + haptic/audio confirmation. | None required. | False emergency activation and authentication trade-offs. | Product requirement. |
| Camera / live assistance | A phone must be held, propped up or surrendered as the viewfinder. | Detachable camera tile or glasses can stream POV while both hands work; wrist is the controller/viewfinder. | Ring shutter + audio cues. | Camera tile or glasses. | Camera privacy and obvious recording state are mandatory. | See docs/camera-strategy.md |

## Design consequences

The strongest scenarios converge on the same architecture: the wrist computer is always present; the main OLED is dark much of the time; haptics/private audio handle confirmation; the ring and deliberate silent articulation provide input without occupying the display; and larger visual work moves to the nearest trusted screen.

Car HUD is therefore a first-class handoff target, not an automotive app running on the wrist. While driving, the system should expose only driving-relevant navigation, vehicle and urgent communication cues. Research on automotive HUDs is mixed: some studies show better forward-view attention allocation, while others show attentional tunneling from visually complex HUDs. AGENT should use the HUD sparsely and suppress ordinary notifications.

Useful HUD references:
- https://pubmed.ncbi.nlm.nih.gov/33840367/
- https://pubmed.ncbi.nlm.nih.gov/37287261/
- https://pubmed.ncbi.nlm.nih.gov/33721620/

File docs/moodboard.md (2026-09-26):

# AGENT-PHONE visual moodboard

This board is for design decisions, not for copying another product. Images are loaded from their original/public hosts where possible; the repository does **not** redistribute those source files. Follow the source link for ownership and context.

The product baseline is: a wrist computer approximately the area of **two Apple Watch Ultra cases side by side**, one uninterrupted almost-borderless OLED, open cuff, hidden tilt mechanism, and no rigid block under the wrist.

## Film & game wrist computers

### REF-01 — Star Citizen mobiGlas

Star Citizen mobiGlas

**Source:** https://robertsspaceindustries.com/en/comm-link/engineering/14466-Design-Notes-MobiGlas

**KEEP:** diegetic personal-computer identity, contextual information, device-to-environment transfer, wide/panoramic information layouts.

**AVOID:** giant public holograms, forearm-scale hardware, always-visible luminous UI.

**WHY:** mobiGlas is useful less as a shape reference than as a model of a personal computer that can move information between the wrist, AR and nearby screens.

### REF-02 — Mass Effect / Andromeda UI

Mass Effect Andromeda UI

**Source:** https://www.behance.net/gallery/51952829/Mass-Effect-Andromeda-User-Interface-Design

**KEEP:** contextual tools, compact visual hierarchy, fast switching between data and world context.

**AVOID:** decorative sci-fi chrome, permanent AR clutter, interfaces that require a huge projected plane.

**WHY:** it demonstrates how a futuristic interface can remain structured and readable instead of becoming a wall of glowing widgets.

### REF-03 — Fallout Pip-Boy

**Source:** https://fallout.bethesda.net/en-US/news/fallout-pip-boy-3000-replica

**KEEP:** unmistakable “computer worn on the body” identity and confidence that the object is a primary computer rather than a notification watch.

**AVOID:** bulk, forearm placement, fixed viewing angle, physical controls surrounding the screen.

**WHY:** AGENT-PHONE should inherit the category confidence without inheriting Pip-Boy ergonomics.

## Real wearables

### REF-04 — Nubia Alpha

Nubia Alpha

**Source:** https://www.golem.de/news/nubia-alpha-im-hands-on-flexibles-display-macht-die-smartwatch-gross-und-dick-1902-139657.html

**KEEP:** proof that an elongated flexible OLED can live on a wrist; screen/body curvature that follows anatomy.

**AVOID:** a narrow portrait strip, thick side housings, phone-app-list UI wrapped around the arm.

**WHY:** it validates display packaging, but AGENT-PHONE uses a wider landscape information surface and a separate open-cuff battery structure.

### REF-05 — Meta Ray-Ban Display + Neural Band

**Source:** https://about.fb.com/news/2025/09/meta-ray-ban-display-ai-glasses-emg-wristband/

**KEEP:** short glanceable interactions, display that is present only when needed, subtle sEMG finger input, glasses + wrist input as one system.

**AVOID:** requiring a second dedicated wristband when AGENT-PHONE already occupies the wrist; locking interaction to one eyewear vendor.

**WHY:** this is the strongest current consumer proof that tiny hand movements and a low-duty-cycle glasses display can reduce dependence on a phone screen.

## Open cuffs & tilting displays

### REF-06 — WristPC concept (Novate reference supplied by the user)

WristPC tilting screen

**Source:** https://novate.ru/blogs/240711/18254/

**KEEP:** **open-bottom cuff** and a screen that physically tilts toward the user instead of forcing wrist rotation.

**AVOID:** keypad-heavy bracelet, 3.5-inch phone-scale display, thick exposed hinge, game controls, general 2011 industrial styling.

**WHY:** this is the closest direct precedent for the two mechanical ideas the user independently arrived at. Everything else should be substantially thinner and cleaner.

### REF-07 — Motorola pivoting wearable concept

Motorola pivoting wearable

**Source:** https://www.trendhunter.com/trends/motorola-pivoting-wearable

**KEEP:** reconfigurable viewing angle and the idea that a wearable display can have more than one useful physical state.

**AVOID:** making the whole band a complex moving display or creating a fragile multi-link mechanism.

**WHY:** it reinforces the value of physical reconfiguration while showing why AGENT-PHONE should keep the hinge local and mechanically simple.

### REF-08 — INFINITY touch bracelet

INFINITY touch bracelet

**Source:** https://www.behance.net/gallery/31231415/Touch-bracelet-INFINITY

**KEEP:** continuous, jewelry-like cuff curvature and clean transitions from rigid electronics to the wrist.

**AVOID:** rigidly enclosing the entire circumference and using the whole bracelet as screen.

**WHY:** useful for silhouette and proportion studies of an open cuff that looks intentional rather than like two battery blocks.

### REF-09 — Sugar pivoting bracelet concept

**Source:** https://www.behance.net/gallery/17612649/Sugar

**KEEP:** display moves relative to the body instead of requiring the user to move the whole arm.

**AVOID:** bulky pivot hardware and decorative shapes that make the mechanism the visual focus.

**WHY:** reinforces the “display moves, wrist stays relaxed” principle.

## Flexible / emissive displays

### REF-10 — FlexEnable bracelet display prototype

FlexEnable bracelet display

**Source:** https://www.infobae.com/2016/02/25/1792717-el-celular-tendra-forma-pulsera/

**KEEP:** screen substrate conforming to a wrist-scale curve and very thin display stack.

**AVOID:** wrapping the active UI around a high-curvature side where text becomes difficult to read.

**WHY:** validates thin flexible display construction; AGENT-PHONE instead keeps its main reading surface nearly flat and uses curves for cuff/battery packaging.

### REF-11 — FlexEnable flexible OLCD wearable

Flexible OLCD wearable

**Source:** https://moov.ooo/article/5eb9fba11b05ee0697dd2c97

**KEEP:** large information area on a wrist and a thin display body.

**AVOID:** very wide rigid metal side rails and an interface that assumes the display itself should wrap around the wrist.

**WHY:** a strong negative/positive reference for balancing screen area against wrist bulk.

### REF-12 — DuPont curved OLED concepts

**Source:** https://www.behance.net/gallery/18236253/Dupont-Displays-Curved-OLED-Display-Concepts

**KEEP:** smooth panel-to-body transitions and the possibility of curving only non-critical visual edges.

**AVOID:** treating curvature as decoration when a flat reading plane is ergonomically better.

**WHY:** informs cover-glass and body transitions around an almost-borderless OLED.

## Rings & spatial control

### REF-13 — IRIS camera smart ring

**Source:** https://www.washington.edu/news/2025/01/08/smart-ring-camera-iris/

**KEEP:** point at a physical device, click/confirm, rotate the hand for continuous control; ring as a context-aware spatial selector.

**AVOID:** making a ring camera mandatory for every interaction or continuously streaming room imagery.

**WHY:** IRIS directly validates the user’s “point at TV/light/speaker and manipulate it” interaction idea.

### REF-14 — Meta Neural Band gesture vocabulary

**Source:** https://about.fb.com/news/2025/09/meta-ray-ban-display-ai-glasses-emg-wristband/

**KEEP:** thumb/finger micro-gestures, wrist rotation as a dial, silent interaction with a display elsewhere.

**AVOID:** duplicating wrist hardware; the sensing should migrate into AGENT-PHONE and/or a ring.

**WHY:** current consumer implementation provides a useful interaction-quality benchmark for Telekinesis.

## Glasses

### REF-15 — Apple Vision Pro gaze + pinch

**Source:** https://support.apple.com/guide/apple-vision-pro/enter-text-and-use-dictation-tana14220eef/visionos

**KEEP:** gaze establishes the target; a small deliberate hand gesture confirms the action.

**AVOID:** requiring headset-scale hardware, persistent immersive UI, or gaze-only commits with no explicit confirmation.

**WHY:** a good interaction reference for optional Agent Glasses: eyes point, ring/hand confirms.

### REF-16 — Meta Ray-Ban Display

**Source:** https://about.fb.com/news/2025/09/meta-ray-ban-display-ai-glasses-emg-wristband/

**KEEP:** display off by default, short private visual answers, photo preview/navigation without pulling out a phone.

**AVOID:** moving the whole product experience into glasses; AGENT-PHONE must remain independently useful.

**WHY:** supports the product thesis that some wrist screen-on time can disappear entirely when a tiny glasses display is present.

## Detachable cameras

### REF-17 — Insta360 GO 3S

**Source:** https://www.insta360.com/blog/news/meet-insta360-go-3s-tiny-mighty-4k-camera.html

**KEEP:** tiny standalone magnetic camera body, wearable/remote mounting, separation of capture sensor from the main display.

**AVOID:** 39 g action-camera bulk as the final target and a second large “Action Pod” UI.

**WHY:** a strong physical precedent for Agent Camera: the sensor can detach and borrow viewfinder/control/compute from the wrist or glasses.

---

## Design synthesis

The recurring pattern is not “make a better smartwatch.” The strongest references split into four roles:

1. **Wrist computer:** a wide, physical, private information surface.
2. **Open cuff:** battery/sensors distributed around the wrist without a hard underside brick.
3. **Telekinesis / ring:** silent eyes-free input and spatial target selection.
4. **Glasses / camera tile / nearby screens:** move pixels and capture away from the wrist when that is ergonomically better.

The render baseline therefore rejects forearm computers, full-circumference screens, large exposed hinges, phone-style portrait app grids, and bulky camera hardware on the wrist.

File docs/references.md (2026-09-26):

# Visual references

See the **[visual moodboard](moodboard.md)** for the image-led comparison board with `KEEP / AVOID / WHY` notes.

This page is a design critique, not a mood-board to copy. External images remain hosted by their original sources; this repository does not redistribute those image files. Rights remain with their respective owners.

## Fallout — Pip-Boy

Official reference: https://fallout.bethesda.net/en-US/news/fallout-pip-boy-3000-replica

**Keep:** unmistakable "computer on the body" identity; dense information; physical confidence.
**Reject:** forearm-scale bulk, fixed viewing angle, deep chassis, requirement to rotate the whole arm toward the face.

Screen should feel like the elegant descendant of this category, not a mini Pip-Boy.

## Star Citizen — mobiGlas

Star Citizen mobiGlas reference

Source: https://www.pcgamer.com/star-citizen-video-show-off-smartwatch-style-ui-called-mobiglas/

**Keep:** landscape information architecture, wrist-local interaction, sense that the wrist is a portal rather than a watch face.
**Reject:** giant holographic plane, weak privacy, impossible outdoor projection assumptions.

Screen gets the landscape ergonomics with a real emissive panel and optional glasses.

## Mass Effect — Omni-tool / Andromeda UI

Mass Effect wearable UI reference

Behance reference: https://www.behance.net/gallery/51952829/Mass-Effect-Andromeda-User-Interface-Design

**Keep:** fast contextual tools, arm-local control, clear mode changes.
**Reject:** projected interface extending far beyond the wrist and constant luminous visual noise.

## Nubia Alpha

Nubia Alpha

Source: https://www.golem.de/news/nubia-alpha-im-hands-on-flexibles-display-macht-die-smartwatch-gross-und-dick-1902-139657.html

**Keep:** real proof that an elongated flexible OLED can wrap with the wrist.
**Reject:** narrow portrait strip, thick side housings and "phone UI wrapped around a wrist."

Screen rotates the information architecture into landscape and keeps the curved volume for battery/strap transition, not for a tall app list.

## Behance — flexible / bracelet explorations

### INFINITY touch bracelet
INFINITY

Project: https://www.behance.net/gallery/31231415/Touch-bracelet-INFINITY

Useful for studying continuous band curvature. Avoid making the whole circumference rigid.

### DuPont curved OLED concepts

Project: https://www.behance.net/gallery/18236253/Dupont-Displays-Curved-OLED-Display-Concepts

Useful for panel-to-body transitions. The visual lesson is smooth curvature, not biomorphic chrome.

### Sugar

Project: https://www.behance.net/gallery/17612649/Sugar

Useful for thinking about a display that pivots relative to its strap. Screen needs a far thinner, hidden mechanism and a much wider landscape panel.

## Pinterest exploration

Pinterest is useful here as a searchable archive of speculative industrial-design patterns, not as technical evidence.

- Fold-out wrist computer: https://www.pinterest.com/pin/668362400960007342/
- Flexible OLED wrist-computer concept: https://ar.pinterest.com/pin/119415827596141305/
- Projection-based bracelet reference: https://in.pinterest.com/pin/bracelet-turns-skin-into-a-touchscreen-display-design-milk--97601516901250271/

**Lesson:** fold-outs and projectors repeatedly become bulky or require a prepared surface. Screen should achieve the ergonomic viewing-angle benefit with one thin physical panel.

## Real interaction references

### Meta Ray-Ban Display + Neural Band

https://about.fb.com/news/2025/09/meta-ray-ban-display-ai-glasses-emg-wristband/

This is the closest commercial validation of the Screen + glasses + wrist-EMG topology. We should not add a second wristband; Screen's own strap/base should host the EMG electrodes.

### Apple Vision Pro
https://support.apple.com/guide/apple-vision-pro/enter-text-and-use-dictation-tana14220eef/visionos

Useful interaction lesson: gaze selects context; a small pinch confirms. Screen should use this when glasses are present, while keeping primary operation possible without glasses.

## Design rules extracted from the references

1. Stay at the wrist, not high on the forearm.
2. Landscape first.
3. The display is one uninterrupted rectangle.
4. Hinge disappears when closed.
5. Battery volume follows the strap direction above/below the screen.
6. Never put a rigid block under the wrist.
7. UI is sparse enough to work on black OLED.
8. Glasses extend Screen; they do not become mandatory.
9. Projection is inspiration for spatial UX, not a V1 display technology.
10. Every render must prove how the object sits on an actual wrist.

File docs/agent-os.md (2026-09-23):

# AGENT hardware × Agent OS

Updated: 2026-09-23

Agent OS:
- Site: https://agentos-bible.vercel.app/
- Source: https://github.com/alex-mextner/AgentOS

AGENT is the hardware expression of Agent OS rather than a second, unrelated platform.

## What maps directly

Agent OS describes itself as:
- app-last;
- local-first;
- agent-native;
- built around durable entities rather than application silos;
- capable of composing task-specific micro-apps;
- explicit about agent capabilities and authority;
- designed for Agent Mesh peer-to-peer connectivity.

Those properties are particularly useful on a small wrist display because the user should not navigate a phone-style grid of full-screen applications.

## AGENT UI model

The primary object on the screen is a **task or entity**, not an app.

Examples:
- a person → messages, call, shared files, next meeting;
- a calendar event → participants, directions, notes, join action;
- a product → compare, buy, track delivery;
- a room → lights, TV, climate, audio;
- a research task → current status, sources, result, follow-up;
- a photo → share, move to TV, ask about it.

Providers can still exist, but they should not dictate the whole UI.

## Micro-apps fit the wide display

The landscape panel is well suited to small temporary compositions:
- chat on the left + photos on the right;
- calendar event + map;
- delivery status + building entry control;
- AI research progress + relevant document;
- TV playback + light/AC controls.

These are not permanent app installations. They are task-specific views assembled from typed capabilities and data sources.

## Always-on agent layer

The low-power controller should not run the whole Agent OS.

It runs a narrow **Agent Edge** service:
- accessory authentication;
- sensor events;
- notification triage;
- haptics;
- screen-off text state;
- tiny local classifier;
- wake requests.

It sends typed events to the suspended application environment.

Example:

```
RingGesture {
  actor: local_user
  gesture: squeeze
  target_hint: living_room_tv
  confidence: 0.96
}
```

The higher-trust Agent OS layer resolves permissions and effects.

## Telekinesis as an Agent OS input provider

Telekinesis should publish:
- text hypotheses;
- confidence spans;
- gesture events;
- gaze targets;
- correction intents;
- provenance: which sensors contributed.

It must not inject arbitrary key events behind the OS's back.

That lets the same silent phrase be interpreted differently depending on context:
- in a chat entity → draft a reply;
- over a product → ask a question;
- over a room → issue a device command;
- while nothing is selected → open the universal command surface.

## Spatial entities

Physical devices should be first-class Agent OS entities:
- TV;
- speaker;
- lamp;
- room;
- another person's AGENT;
- camera tile;
- glasses.

The ring/glasses stack estimates **which entity the user is pointing at**. Agent OS then handles identity, capability, ownership, transport and action.

This separation is important: geometry says "that object"; the entity system says "Living Room TV owned by this household, with these allowed actions."

## Air transfer

"Throwing" a photo or card to another screen is modeled as an explicit entity transfer:

1. select/grab an entity;
2. spatial input proposes a target entity;
3. UI/haptic preview confirms target;
4. capability layer checks whether the action is allowed;
5. Agent Mesh/local transport sends the object or grants access;
6. both devices receive an effect receipt.

The gesture is only the front-end. The transfer remains inspectable and revocable.

## Local-first policy

Raw high-rate sensor streams should remain local whenever possible:
- sEMG;
- PPG;
- gaze;
- camera hand tracking;
- ring IMU;
- throat/neck sensor data.

Derived events such as `pinch`, `target=TV`, or a text hypothesis are what normally enter the entity/action layer.

Cloud AI can be used for explicitly chosen workloads, but local state should not depend on a vendor cloud to remain usable.

## App-last marketplace

The commercial layer does not need an app store full of monoliths.

A seller/integrator can expose:
- typed data source;
- action;
- widget/component;
- model/tool;
- device driver;
- transport provider.

Agent OS composes those pieces into the current task.

This directly supports the project's "hyper-targeting without ads" idea: a user-controlled local agent may decide that a need exists, ask permission, then query competing providers. It should not sell a behavioral profile or allow hidden sponsored ranking.

## Hardware implications

Agent OS should eventually expose hardware capabilities such as:

```
display.sparse_indicator
display.wrist_surface
haptic.pulse
telekinesis.text
telekinesis.gesture
spatial.point
camera.context
camera.capture
audio.private_tts
cellular.low_power
uwb.range
health.read
```

Each should have explicit permissions and power-cost metadata.

## Boot and persistence

Agent OS should optimize for:
- suspend/resume, not repeated boot;
- crash-safe durable entities;
- small always-on service boundary;
- incremental UI composition;
- local encrypted history;
- ability to continue core actions offline.

The hardware project should not create a separate mobile-app abstraction that Agent OS later has to undo.

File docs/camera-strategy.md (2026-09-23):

# Camera strategy

Updated: 2026-09-23

## Problem

A wrist is a poor primary camera position. Framing requires an unnatural arm pose, the angle is wrong for many subjects, and a wide wrist computer already has enough thickness pressure.

Glasses are better for point-of-view capture and spatial understanding, but they do not always produce the composition, lens choices or image quality people expect from a phone camera.

AGENT therefore should not pretend that one fixed wrist camera solves photography.

## Proposed camera system

### 1. Glasses camera = context camera

The glasses camera is always the best place for:
- spatial mapping;
- identifying what the user points at;
- reading QR codes / labels;
- low-friction first-person memories;
- video calls from the user's perspective;
- hand tracking for ring gestures.

It is *not* the only camera.

### 2. Detachable camera tile = deliberate photography

A small magnetic camera tile is the preferred phone-camera replacement.

The tile can:
- dock to the wrist base or battery wing for charging;
- clip to clothing / a pendant / bag strap;
- be held between two fingers for conventional framing;
- stick magnetically to metal surfaces;
- use the wrist display or glasses as a live viewfinder;
- use the ring as shutter / zoom / exposure control.

This is much more natural than rotating the entire wrist computer toward the subject.

A useful existing reference is the detachable/wearable direction of Hohem Eyepic:
https://www.hohem.com/product/eyepic

And the scale benchmark is Insta360 GO 3S: about 25.6 × 54.4 × 24.8 mm and 39.1 g. AGENT's camera tile should be materially thinner and lighter than that because it can borrow compute/storage/viewfinder from the wrist computer.

https://onlinemanual.insta360.com/go3s/en-us/faq/specs/hardware

### 3. Wrist camera = optional utility sensor

If a wrist camera exists, keep it small and use it for:
- document/QR scan while holding an object;
- environment context;
- emergency capture;
- device tracking for spatial gestures.

Do not optimize the industrial design around it.

## Prototype camera modules

### Raspberry Pi Camera Module 3

A practical first prototype camera:
- Sony IMX708;
- 12 MP;
- autofocus;
- HDR mode;
- 25 × 24 × 11.5 mm;
- standard or 120° wide lens;
- about $25–$38.50 depending version.

Official:
https://www.raspberrypi.com/products/camera-module-3/

This is too thick for a polished final tile but excellent for proving the camera workflow.

### Waveshare OV5647 OIS module

For stabilization experiments:
- 5 MP;
- dual-axis optical stabilization;
- ±5° compensation;
- 6 g;
- about $52.

https://www.waveshare.com/OV5647-70-5MP-OIS-Camera.htm

The resolution is modest, but it proves that the tile can have real optical stabilization independent of the wrist.

### Arducam IMX219 autofocus USB

Useful when the main prototype exposes USB rather than CSI:
- 8 MP;
- autofocus;
- UVC;
- about $34.99.

https://www.arducam.com/8mp-hdr-autofocus-usb-camera-module-with-metal-housing-1080p-mini-uvc-usb2-0-webcam-a219.html

## Final-product direction

For a custom board, target:
- 1/1.3"–1/1.7" main sensor if thickness permits;
- OIS or sensor-shift if the module can stay under roughly 8–10 mm;
- autofocus;
- one good wide/normal lens rather than multiple mediocre cameras;
- computational multi-frame HDR;
- burst buffer in the camera tile;
- UWB/BLE for discovery and low-rate control;
- high-rate transfer over Wi-Fi Direct or a dock connector.

A second telephoto camera belongs in an optional photography accessory rather than making the base wrist computer thicker.

## Viewfinder model

The user should be able to choose any display:
- wrist panel for ordinary framing;
- glasses HUD for eye-level framing;
- TV/monitor for tripod-style shots;
- another AGENT device as a remote monitor.

The camera tile is a sensor/lens/buffer device, not a miniature phone.

## Ring controls for photography

Suggested vocabulary:
- point camera + ring tap: focus;
- ring squeeze: shutter;
- thumb slide on ring: exposure compensation;
- double tap: switch photo/video;
- pinch + wrist roll: zoom;
- long squeeze: lock AE/AF;
- two-ring chord: manual parameter mode.

## Privacy

Glasses and tile cameras need unmistakable capture indication. Spatial mapping can be processed locally without retaining raw video. Recording a photo/video and background scene understanding are separate permissions and separate visible states.

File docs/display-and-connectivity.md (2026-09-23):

# Display, silicon, battery and connectivity

## Display recommendation

### V1: LTPO OLED

The first prototype should target a custom **LTPO3-class OLED** or equivalent low-refresh emissive OLED:
- true per-pixel emission and deep black;
- ~1 Hz or lower low-power idle modes;
- wide viewing angle because the device is often tilted;
- excellent contrast for sparse screen-off indicators;
- thin flexible substrate options.

A polarizer-free stack is especially attractive. Samsung Display's Eco²OLED architecture reports 33% higher light transmission and up to 25% lower panel power versus a conventional polarizer-based OLED stack:
https://global.samsungdisplay.com/31141?type=main

Treat those numbers as vendor-specific, not a guaranteed Screen saving.

### Tandem OLED

Tandem OLED stacks can trade extra emissive layers for brightness, lifetime and/or lower operating current. If a supplier can deliver a thin custom wearable panel, it is worth evaluating together with polarizer-free optics.

### MicroLED

MicroLED is now a real smartwatch technology, not science fiction. Garmin's 2025 fēnix 8 Pro MicroLED uses more than 400,000 individual LEDs and advertises up to 4,500 nits:
https://www.garmin.com/en-US/newsroom/press-release/wearables-health/introducing-fenix-8-pro-the-first-ever-smartwatches-from-garmin-with-inreach-technology-for-sate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

However, the MicroLED model is significantly more expensive and has lower quoted smartwatch battery life than Garmin's AMOLED sibling. For Screen, MicroLED is a future premium option; OLED is the lower-risk V1.

## Screen power strategy

Hardware only helps if the UI cooperates:
- black is the default canvas;
- screen stays fully off during blind composition;
- a few status pixels may show listening / confidence / sent;
- refresh drops aggressively for static cards;
- animations are short and local;
- video defaults to handoff;
- optional glasses may show transient text while the wrist screen stays dark.

## Compute platform

Qualcomm's Snapdragon Wear Elite, announced in March 2026, is unusually close to Screen's requirements:
- 3 nm wearable architecture;
- dedicated NPU;
- 5G RedCap;
- Micro-Power Wi-Fi;
- Bluetooth 6;
- UWB;
- GNSS and NB-NTN;
- Linux / Android / Wear OS support.

Official overview:
https://www.qualcomm.com/wearables/products/snapdragon-wear-elite-platform

This is a reference target rather than a locked supplier decision. The architecture should allow an equivalent low-power Linux/Android wearable SoC.

## Cellular

**eSIM only.** There is no physical SIM tray.

5G RedCap is preferred because it is designed for reduced-capability devices that do not need flagship-phone throughput. Screen should prioritize standby efficiency, messaging, calls, navigation and AI coordination over sustained video bandwidth.

Large model inference should normally be hybrid:
- local intent / input decoding / privacy-sensitive features on-device;
- nearby trusted devices when present;
- cloud for large AI workloads;
- progressive results so the user can leave the main display off.

## Battery architecture

Use energy in Wh for engineering decisions even though mAh is convenient for product discussion.

At ~3.85 V nominal:
- 150 mAh ≈ 0.58 Wh;
- 2,500 mAh ≈ 9.6 Wh;
- 3,000 mAh ≈ 11.6 Wh.

The detachable module should not carry phone-scale energy. Its reserve cell exists to survive detachment and short hand-held use. The base and two curved wings carry most energy.

### Cell technology for prototypes

Use proven Li-ion/Li-poly pouch chemistry with high-silicon-anode variants where a reputable supplier can certify cycle life and swelling. Split cells into mechanically isolated curved/segmented cavities instead of forcing one large pouch around a tight bend.

Research tracks:
- semi-solid / solid-state cells for higher packaging freedom;
- structural battery strap segments;
- curved custom pouch cells;
- wireless/galvanic power bridge across the hinge carrier.

Do not base the first ergonomic prototype on lab-only chemistry.

## External endurance pack

An optional external battery can attach by a flat, clothing-integrated cable or decorative illuminated cable and live under clothing at the torso. It is an accessory, never required for normal operation.

The core industrial design must remain useful with no cable attached.

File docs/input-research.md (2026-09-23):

# Deep research: keyboardless input

Updated: 2026-09-23

## Executive conclusion

A keyboard-free Screen is plausible, but no single sensor is ready to replace a keyboard for arbitrary text in every setting. The strongest architecture is **multimodal and personal**:

1. wrist sEMG + IMU for mode control, selection, punctuation and corrections;
2. deliberate silent articulation for primary private text entry;
3. gaze for target selection when glasses are worn;
4. private TTS / bone-conduction readback instead of keeping the screen lit;
5. ordinary voice dictation when privacy allows.

The system should learn a user's articulation and gesture signatures over time. It should fuse confidence across sensors rather than pretend that one experimental modality is universally reliable.

## Important distinction: silent speech is not thought reading

MIT AlterEgo demonstrates that deliberate internal/silent articulation can create measurable neuromuscular signals at the face and neck. MIT explicitly describes it as conscious silent voicing and says the device does not read arbitrary thoughts.

- MIT FAQ: https://www.media.mit.edu/projects/alterego/frequently-asked-questions/
- 2018 paper: https://www.media.mit.edu/publications/alterego-IUI/

That is the product model for Telekinesis: the user deliberately enters an input state and silently articulates. We should not depend on involuntary tongue motion during ordinary thought, even if future research discovers useful correlates.

## Technology landscape

| Modality | Wear location | What it can sense | Evidence / current result | Product view |
|---|---|---|---|---|
| Surface EMG | wrist | finger intent, pinch, wrist motion, chords | Meta ships Neural Band with Ray-Ban Display; subtle muscle signals | **V1 control layer** |
| Surface EMG | face/neck | deliberate silent articulation | AlterEgo reported 92% median word accuracy in its 2018 task | **High-value R&D** |
| Acoustic sonar | glasses | lip/jaw/mouth motion | EchoSpeech: up to 31 commands; low-power wearable | **V1/V2 research** |
| Acoustic sonar | glasses | open-vocabulary silent speech | SoniSpeech 2026 baseline: 26.3% WER, 5,356 unique words | **Promising, not solved** |
| Acoustic sonar | headphones | TMJ motion | HPSpeech: 8 commands, >90% across 18 participants | **Very practical accessory** |
| Acoustic sonar | nose | tongue/mouth/breath gestures | EchoNose: 16 gestures, 93.7% average in 10 participants | **Great lab signal, poor daily form factor** |
| Optical PPG | neck | under-skin blood/neck modulation from articulation | PPGSpeech: 81.41% ±9.74 on 15 commands | **Direct match to necklace idea** |
| Textile strain | neck | throat micromovements | Cambridge graphene choker: 95.25% in reported decoding task | **Strong necklace/choker path** |
| Ultrasound imaging | under chin | direct tongue shape/motion | SottoVoce demonstrates silent speech from ultrasound images | **Too bulky/coupled for V1** |
| Acoustic eye tracking | glasses | gaze direction | GazeTrak: 3.6° same-session; embedded 30 Hz path ~95 mW | **Good for coarse targeting** |
| Acoustic wrist sonar | wrist | 3D hand pose / object interactions | EchoWrist reports smartwatch-scale all-day sensing | **Optional secondary channel** |
| Camera/IR | glasses/neck | mouth/chin/eyes | technically strong but high privacy/power burden | **Avoid as required input** |

## Evidence notes

### Wrist sEMG

Meta's Neural Band is the clearest evidence that subtle wrist muscle activity has crossed from research into a consumer product. Meta describes EMG control for scrolling/clicking and a path toward writing messages using subtle finger movements.

Source: https://about.fb.com/news/2025/09/meta-ray-ban-display-ai-glasses-emg-wristband/

For Screen, place dry sEMG electrodes in the strap/base where skin contact is already expected. Target gestures:
- thumb–index tap and double tap;
- pinch and squeeze;
- thumb swipe/rub against the index finger;
- finger chords;
- very small attempted motions that do not need to become visually obvious.

### IMU + PPG wrist gestures

Apple Watch already supports tap-style and wrist-flick interactions using its sensor stack. Telekinesis should add:
- rapid flick away-and-back;
- roll/pronation and return;
- inward wrist flex and return;
- hold/squeeze as a mode modifier.

These gestures are best used as editing/navigation primitives, not as an alphabet.

### Acoustic glasses

Cornell EchoSpeech uses inaudible acoustic sensing on ordinary-looking glasses to infer unvoiced mouth movements:
https://news.cornell.edu/stories/2023/04/ai-equipped-eyeglasses-can-read-silent-speech

The important 2026 reality check is SoniSpeech. It scales acoustic eyewear to open vocabulary, but its published baseline is still 26.3% WER. That is exciting research, not yet invisible-keyboard quality:
https://arxiv.org/abs/2608.00803

This suggests a practical hybrid: acoustic glasses provide phonetic evidence; a personalized language model, wrist gestures and explicit confirmations reduce errors.

### Headphones / earbuds

HPSpeech reuses headphone speakers to emit inaudible signals and senses temporomandibular-joint movement with an inward microphone. In an 18-participant study it recognized eight commands at >90% accuracy. The authors note that ANC headphones already contain much of the required hardware.

Paper: https://czhang.org/assets/pdf/HPSpeech.pdf

For Screen this is attractive because earbuds/headphones already solve private TTS output. Future earbuds could be both input sensor and output channel without a visible extra device.

### Tongue sensing

The user's tongue idea is technically credible, but the best evidence is for **deliberate tongue gesture**, not passive thought decoding.

EchoNose sends inaudible acoustic signals through the nostril/oral cavity and distinguished 16 speech/tongue/breath gestures at 93.7% average accuracy. Its study includes tongue tap, double-tap and directional swipes along the palate.

ACM program summary: https://ubicomp.hosting.acm.org/ubicompiswc2023_wp/program/iswc-toc/

This is excellent evidence that tongue gestures can be a high-bandwidth private command channel. A nose interface is not the desired consumer form factor, so the research task is to move comparable sensing to glasses, earbuds, a necklace or a comfortable collar.

### Light "under the skin": PPG

PPGSpeech is particularly relevant to the proposed neck wearable. It uses multi-wavelength photoplethysmography in a necklace-style device and finds that subtle neck muscle movement during silent articulation modulates the optical signal.

In a 16-participant, 15-command study the user-dependent model reported 81.41% ± 9.74 accuracy, plus experimental speech reconstruction.

IEEE: https://ieeexplore.ieee.org/document/11271667/

This is the closest existing research to "scan with light under the skin" in a compact neck form factor. It should be a first-class Telekinesis experiment.

### Textile choker / vibration and strain

A graphene-coated textile strain sensor around the throat captures micromovements from silent articulation. The 2024 Cambridge work reports 95.25% decoding accuracy in its evaluated task:
https://www.nature.com/articles/s41528-024-00315-1

A 2026 Nature Communications system extends throat sensing to continuous communication in a small stroke-patient study:
https://www.nature.com/articles/s41467-025-68228-9

This is more mechanically simple than ultrasound imaging and may pair naturally with PPG in the same soft collar.

### Ultrasound tongue imaging

SottoVoce places an ultrasound imaging sensor under the jaw and uses tongue/internal articulation images for silent speech:
https://lab.rekimoto.org/projects/sottovoce/

It directly observes the articulator we care about, but conventional ultrasound needs good mechanical coupling and a transducer under the chin. Keep this as an R&D benchmark, not a V1 industrial-design assumption.

### Gaze without a camera

GazeTrak mounts one speaker and four microphones on each side of glasses and uses inaudible acoustic reflections around the eye. The published system reports 3.6° accuracy in the same remounting session and an embedded implementation around 95.4 mW at 30 Hz.

https://www.scifilab.org/copy-of-posesonic-1

That is sufficient to explore coarse UI target selection. For tiny text insertion points, camera/IR eye tracking remains more mature. Screen should therefore use gaze to select regions/cards and pinch to confirm, not rely on gaze-only text editing.

### Acoustic wrist hand tracking

EchoWrist uses miniature speakers and microphones on a wristband to reconstruct hand pose and recognize interactions. Cornell reports it fits smartwatch-scale hardware and can run all day on a standard smartwatch battery.

https://bowers.cornell.edu/news-stories/echowrist-uses-sonar-ai-track-hand-movements

Because Screen already needs microphones/speakers for calls and interaction, a low-duty-cycle acoustic hand-pose mode is worth prototyping after sEMG.

## Proposed Telekinesis sensor stack

### On Screen itself
- 6–8 dry sEMG electrodes distributed through the base/strap contact area;
- 6-axis IMU with high-rate burst mode;
- optical PPG sensor;
- 1–2 tiny acoustic emitters + microphones for hand-pose experiments;
- haptic actuator;
- touch screen as fallback;
- microphones for ordinary dictation.

### Optional glasses
- low-duty-cycle emissive display;
- gaze tracking, with acoustic sensing as a low-power research track;
- microphones/speakers for silent-speech acoustics and TTS;
- camera optional, not required for base interaction.

### Optional earbuds/headphones
- inward ANC microphone + speaker-based acoustic sensing for TMJ motion;
- private TTS;
- voice dictation;
- potentially bone-conduction output.

### Optional neck band / necklace
- multi-wavelength PPG;
- textile strain sensor around throat contact points;
- contact microphone / vibroacoustic pickup;
- optional electrodes for neck sEMG.

The neck accessory should look like jewelry or a soft collar, not medical equipment.

## Interaction vocabulary

Telekinesis should separate **continuous language** from **editing commands**.

Silent articulation:
- free-form message text;
- search queries;
- AI instructions;
- short command phrases.

Wrist/finger gestures:
- arm/disarm input;
- confirm/send;
- undo last word;
- choose between 2–4 candidates;
- punctuation;
- cursor/selection movement;
- cancel.

Gaze:
- pick app/card/object;
- point to a photo, message, light or TV;
- establish context before a gesture.

TTS/haptics:
- word/phrase confirmation;
- confidence warnings;
- private readback;
- no need to illuminate the full display.

## Personalization strategy

The model should have a shared encoder plus a tiny per-user adaptation layer. Enrollment starts with short prompted phrases, then improves from accepted/rejected corrections.

Important principles:
- never silently train on unarmed private behavior;
- keep raw biosignals local by default;
- expose "forget my calibration";
- maintain per-context profiles because walking, eating and resting change signals;
- fuse language-model priors only after preserving a way to recover literal input.

## What to prototype first

**P0 — software simulation**
- gesture grammar and confidence model;
- screen-off composition state machine;
- TTS correction loop.

**P1 — wrist**
- commodity multichannel sEMG development board + IMU;
- implement tap, double tap, pinch, squeeze, wrist flick, roll and flex;
- compare against optical/IMU-only recognition.

**P2 — neck**
- multi-wavelength reflective PPG around the neck;
- soft strain sensor;
- 20–50 phrase personal vocabulary;
- test whether PPG + strain outperforms either alone.

**P3 — glasses/headphones**
- reproduce EchoSpeech/HPSpeech-style inaudible acoustic features;
- gaze target + pinch confirmation;
- fuse with language model and wrist editing gestures.

**P4 — open vocabulary**
- train personalized silent-speech model;
- measure WER, correction rate, time-to-compose and social comfort;
- do not ship until correction overhead is lower than simply pulling out a keyboard.

## Success metrics

- words per minute after 1 hour / 1 week / 1 month of adaptation;
- word error rate before and after user correction;
- gestures per corrected word;
- false activation per hour;
- input energy per hour;
- percentage of messages composed with the main display fully off;
- time looking at a display per composed message;
- confidence calibration: when the system says 90%, is it actually right about 90% of the time?

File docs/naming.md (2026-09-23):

# Naming

## Working product name: AGENT

**AGENT** currently fits the concept best because the hardware is not primarily a watch or a phone. It is a physical endpoint for a personal agent and Agent OS.

The name should stay product-like rather than be expanded into an acronym.

Possible hierarchy:
- **AGENT** — device family;
- **AGENT One** — first general-purpose model, if a model name is needed;
- **AGENT Dive** — secure-clasp / water-focused version;
- **Agent Ring** — tactile and spatial input accessory;
- **Agent Glasses** — optional display / gaze / spatial accessory;
- **Agent Camera** — detachable camera tile.

## Passport

**Passport** is strong for the identity / residency layer rather than necessarily the physical hardware SKU.

Possible usage:
- "Your AGENT is your Passport."
- Passport credential / Passport wallet.
- Resident Passport as a cryptographic identity object that can live on AGENT but is not trapped in the hardware.

This distinction avoids implying that losing the device means losing identity.

## Screen

**Screen** remains useful as a plain-language category term:
- wrist screen;
- personal screen;
- primary Screen surface.

It is deliberately literal, but as a brand it is hard to search and difficult to distinguish from the generic noun.

## Telekinesis

**Telekinesis** is the working subsystem name for interaction without a visible keyboard:
- deliberate silent articulation;
- tiny finger movements;
- wrist gestures;
- ring input;
- gaze;
- spatial pointing;
- haptic/TTS correction.

It should be described as multimodal interaction, not as thought reading.

## Category language

Useful descriptive phrases:
- wrist computer;
- personal wrist computer;
- wearable personal computer;
- agent device;
- personal agent hardware;
- wrist screen.

Avoid forcing the product into an existing category before the interaction model is validated.

## Avoid for now

- **smartwatch** — anchors expectations to fitness/notifications and a small square face;
- **phone** — implies portrait apps, games and video consumption;
- **PDA** — historically related but culturally dated;
- **communicator** — useful in science fiction, but generic as a product name;
- **neural interface** — overclaims the sensing stack;
- **AI pin** — anchors the product to a failed/limited product category rather than its actual wrist interaction.

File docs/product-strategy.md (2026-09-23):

# Product and distribution strategy

Status: hypothesis

## Base device

The base AGENT wrist computer is intended to be distributed free to a limited waitlist / early-resident cohort.

The purpose of free distribution is not to hide hardware cost. It is to maximize the installed base of a new interaction platform and to learn from real use before optimizing hardware margin.

## Paid extensions

Candidate commercial extensions:
- Agent Ring;
- multiple-ring kit;
- Agent Glasses;
- detachable Agent Camera;
- larger / external endurance battery;
- Dive cuff and clasp;
- specialist health sensors;
- premium materials;
- industrial / field versions;
- repair parts and replacement modules;
- enterprise integrations and support.

## Open platform

Core interfaces should be open enough for third parties to build:
- sensors;
- straps/cuffs;
- camera modules;
- power modules;
- Agent OS providers;
- data sources;
- spatial devices;
- local AI tools.

A free base device only works economically if accessories are genuinely optional and the platform does not deliberately cripple third-party alternatives.

## Waitlist

The waitlist should measure more than demand.

Useful questions:
- wrist size;
- dominant hand;
- willingness to wear a wide landscape device daily;
- desired battery life;
- interest in ring/glasses/camera;
- current phone usage categories;
- willingness to test screen-off text;
- professional/domain expertise;
- availability for structured prototype feedback.

Do not require sensitive identity or behavioral data just to join.

## Success metrics

Prototype programme:
- daily wear rate;
- median hours worn;
- interactions completed without taking out another device;
- messages composed with display off;
- display-on minutes per day;
- number of successful handoffs to TV/glasses;
- comfort complaints by wrist size;
- accessory attachment rate;
- battery endurance;
- failure/repair rate.

Business model:
- base hardware cost;
- accessory gross margin;
- support cost per active device;
- replacement-module rate;
- third-party ecosystem revenue if any;
- user retention independent of accessory purchases.

## Avoid lock-in

AGENT should not become "free hardware that only works if you buy proprietary services."

Design constraints:
- exportable data;
- replaceable service providers;
- open device APIs;
- no mandatory behavioral ads;
- no required cloud account for local core functions;
- accessories discoverable through standard/authenticated protocols where practical.

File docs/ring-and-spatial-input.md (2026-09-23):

# Agent Ring and spatial input

Updated: 2026-09-23

## Purpose

A ring is not a miniature smartwatch. Its job is to give AGENT tactile, eyes-free and spatial controls that remain available when the wrist display is dark or when optional glasses are the active display.

The ring should work alone for simple input and fuse with the wrist device, glasses cameras, UWB anchors and room context for spatial interaction.

## Interaction vocabulary

### Eyes-free tactile controls
- tap / double tap the ring with the thumb;
- press or squeeze two sides of the ring;
- slide or rub the thumb along a capacitive arc;
- short/long stroke for scroll and scrub;
- "virtual rotation": pinch the ring and drag around its outer capacitive arc without physically rotating the ring;
- physical rotation is an optional later experiment, not a V1 requirement;
- tap ring against another finger for discrete commands.

Suggested default mappings:
- vertical thumb slide: volume / brightness / list scroll;
- tap: play/pause, accept, select;
- double tap: next item;
- squeeze: back / cancel or modifier;
- squeeze + slide: coarse/fine adjustment;
- long press: arm Telekinesis / spatial mode.

## Mid-air gestures

The ring IMU provides a stable local motion trace while the wrist IMU provides forearm orientation. Optional glasses cameras provide visual hand pose and scene geometry.

This enables:
- point at a TV, lamp, speaker or air conditioner to select it;
- point + twist wrist to change volume / temperature / dimming;
- point + tap to toggle;
- move a selected object from the wrist display toward another screen;
- "air copy": grab a card/photo/object, point to another device, release;
- switch apps by swiping the hand laterally in front of the wrist device;
- rotate 3D objects by pinching and rotating the hand;
- resize windows on glasses with pinch-spread gestures;
- drag content between wrist, glasses, TV and another person's AGENT.

These must be explicit, mode-gated gestures. Random hand movement must not cause actions.

## Why the idea is technically credible

### RingGesture
RingGesture is a published mid-air typing system that uses an IMU-equipped ring and deep-learning word prediction. It reported 27.3 WPM average and 47.9 WPM peak in its evaluation.

https://pubmed.ncbi.nlm.nih.gov/39250409/

This makes a ring a credible fallback text-entry modality, especially when glasses provide a virtual keyboard or spatial target.

### PointRing
PointRing (IMWUT 2026) studies device selection using a UWB + IMU smart ring without repeated manual calibration.

DOI: https://doi.org/10.1145/3810225

### SeleCon
SeleCon demonstrates the same core interaction pattern at wrist scale: inertial sensing detects pointing and UWB identifies the target device, with UWB activated only when needed to save power.

https://pmc.ncbi.nlm.nih.gov/articles/PMC5909733/

### IRIS
University of Washington's IRIS ring combines a camera, Bluetooth, IMU and battery. It recognizes the pointed-at device from the scene and uses contextual gestures for control.

https://iris.cs.washington.edu/

### PeriSense
PeriSense shows that capacitive proximity around a ring can sense adjacent fingers and multi-finger gestures up to roughly 2.5 cm in its experiments.

https://pmc.ncbi.nlm.nih.gov/articles/PMC7411889/

### picoRing
picoRing is especially interesting for AGENT because it demonstrates fully passive rings read by a wristband over inductive coupling. The paper reports 1.5 g ring prototypes supporting pressing, sliding and scrolling without a battery in the ring.

https://arxiv.org/abs/2411.13065

This suggests a long-term architecture where the wrist computer powers/reads one or more ultra-light rings.

## Prototype architecture

### V0 — fast DIY ring
- Seeed XIAO nRF52840 Sense;
- onboard IMU;
- copper / flex-PCB capacitive arc;
- one thin force or strain element for squeeze;
- tiny LiPo;
- BLE to AGENT;
- PETG shell.

This is larger than a final ring but is fast to build.

### V1 — custom PCB
- nRF54L-class BLE MCU or equivalent;
- BMA400-class low-power accelerometer plus gyro only when spatial mode is armed;
- segmented capacitive electrodes around the outer circumference;
- one or two strain gauges / force sensors;
- haptic click actuator if packaging allows;
- 15–30 mAh curved battery;
- inductive charging.

### V2 — spatial ring
Add UWB only if target selection needs it. Qorvo QM35825 is a compact 4.08 × 3.38 × 0.63 mm UWB SoC and supports ranging plus angle-of-arrival functions.

https://www.qorvo.com/products/p/QM35825

For the first room-control prototype, UWB does not need to be in every appliance. A small UWB/BLE bridge can be attached near a TV or speaker and mapped to the device in Agent OS.

### V3 — battery-free companion rings
Prototype a picoRing-style passive ring whose switches/capacitive elements are inductively read by the wrist base. This is attractive for a second ring on another finger because it avoids charging two rings.

## Glasses fusion

Glasses are the best spatial reference because their camera sees what the user sees.

Fusion pipeline:
1. glasses estimate device positions and hand keypoints;
2. ring IMU supplies high-rate orientation/motion;
3. wrist IMU supplies forearm pose;
4. UWB provides identity/range when ambiguous;
5. Agent OS resolves the selected durable entity (TV, speaker, light, person, file);
6. a deliberate click/squeeze commits the action.

The camera should not be continuously uploaded. Scene semantics and hand/device pose should be reduced locally to compact features when possible.

## Health sensors in the ring

Possible additions:
- PPG for pulse / HRV / SpO2 experiments;
- skin temperature;
- skin-contact / wear detection;
- EDA only if electrode contact is reliable;
- overnight motion / sleep sensing.

Health sensing competes directly with ring thickness, battery and electrode area. For the first control ring, interaction quality takes priority. A dedicated health ring can be a later accessory.

## Multi-ring mode

Two rings can create a richer chord vocabulary:
- thumb-to-index ring: pointer/select/scroll;
- middle-finger ring: modifier / clutch;
- pinch between two instrumented fingers: 3D grab;
- relative orientation between rings: rotate/scale;
- ring-to-ring touch: explicit pairing or transfer gesture.

The system should remain fully useful with one ring. Multiple rings are an optional expert configuration.

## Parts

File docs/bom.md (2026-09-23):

# Prototype BOM and sourcing plan

Updated: 2026-09-23
Currency: USD unless noted. Prices are single-unit web prices observed on the date above and exclude VAT, shipping and import fees.

The prototype should be split into **ergonomics**, **electronics**, **input**, and **camera** builds. Trying to fit every final subsystem into the first cuff will make the object too thick and teach us the wrong ergonomic lessons.

## 1. Display: the hardest single part

### Best off-the-shelf match found: 4.01" flexible bar AMOLED

Freetech currently lists a 4.01-inch flexible AMOLED for wearable devices:
- 960 × 162;
- MIPI interface;
- capacitive touch option;
- MOQ 1;
- Alibaba price range around **$50–$240** depending configuration.

https://www.alibaba.com/product-detail/Freetech-4-01-Inch-Flexible-AMOLED_1600318913593.html

A related HX401RAN10A panel lists approximately:
- outline 27.39 × 111.74 × 0.81 mm;
- active area 19.99 × 99.94 mm;
- 192 × 960;
- MIPI;
- RM69330 driver.

https://www.ecer.com/corp/details-uuuf92d-p1k3nvk-4-01-inch-flexible-amoled-display-192-960-dots-mipi-interface-driving-ic-rm69330-350c-d.html

**Recommendation:** buy one or two of these first. It is the closest readily sourced single continuous OLED to the desired long landscape shape.

**Limitation:** ~20 mm active height is visibly narrower than the target "two Watch Ultras side by side". It proves the interaction and hinge, not final proportions.

### Fallback display for software work

Waveshare's 1.75" AMOLED modules are small and square-ish, so they are wrong for industrial design but useful for firmware/UI bring-up.

Vendor:
https://www.waveshare.com/

Do not let this fallback redefine the product shape.

### Donor-panel route

A donor flexible phone OLED offers excellent pixels but creates three problems:
1. most are much taller than needed;
2. the panel cannot simply be cut;
3. reverse-engineering the MIPI initialization, touch and power rails may cost more time than the screen.

Use donor phone panels only if a known driver board exists.

### Custom panel later

After wrist geometry is validated, request a custom ~100 × 32–34 mm AMOLED/flexible OLED sample from vendors such as Wisecoco or Freetech.

https://www.wisecocodisplay.com/

Do **not** pay custom-panel NRE before the cardboard/PETG and bar-AMOLED prototypes confirm the dimensions.

## 2. Wrist electronics — P0 ergonomic prototype

Goal: prove comfort, cuff, battery-wing geometry, tilt, detachment and screen readability.

| Part | Qty | Current price / estimate | Notes |
|---|---:|---:|---|
| Freetech 4.01" flexible AMOLED | 1 | **$50–240** | Main long OLED, MOQ 1 listing |
| XIAO nRF52840 Sense | 1 | **$15.99** | BLE + IMU; can run cuff sensors without Linux |
| 1000–1200 mAh flat LiPo | 2 | **~$5–15 each** | One in each cuff wing for the crude prototype |
| 100–200 mAh thin LiPo | 1 | **~$4–10** | Reserve cell in detachable module |
| Charger + protection + regulators | 1 set | **$15–35 est.** | Use reputable protected cells/modules |
| Haptic actuator + driver | 1 | **$8–15 est.** | Tiny input feedback |
| Magnets, pogo pins, latch hardware | 1 set | **$15–30 est.** | Detach mechanism |
| PETG + TPU/liner allocation | — | **$10–20 est.** | Printed cuff and soft contact parts |
| FPC/wire/connectors | — | **$15–30 est.** | Display and service wiring |

**P0 target:** roughly **$150–$400**, dominated by which display/controller configuration the vendor ships.

The application UI may run on a nearby laptop during this stage. That is intentional.

## 3. Functional wrist prototype — P1

### Main compute option A: Raspberry Pi Zero 2 W

Official price: **$15**.
Size: 65 × 30 mm.
512 MB RAM, Wi-Fi/BLE, CSI camera.

https://www.raspberrypi.com/products/raspberry-pi-zero-2-w/

Pros:
- cheap;
- mature Linux;
- camera support;
- enough to validate Agent OS protocols and UI streaming.

Cons:
- too long and power-hungry for the final device;
- no MIPI-DSI output suitable for every raw AMOLED without bridge hardware.

Treat it as a temporary engineering board.

### Main compute option B: Compute Module 5, bench only

Current official entry price: **from $67.50**.
Size: 55 × 40 × 4.7 mm.
eMMC options up to 64 GB.

https://www.raspberrypi.com/products/compute-module-5/

This is useful when the camera/UI stack needs much more CPU, but it should live off-wrist or in an intentionally oversized engineering cuff.

### Final-compute reference: Snapdragon Wear Elite

Not presently a hobbyist single-board purchase, but the architecture matches the product:
- 3 nm;
- NPU up to 12 TOPS;
- 5G RedCap;
- low-power islands;
- eMMC up to 64 GB.

https://www.qualcomm.com/wearables/products/snapdragon-wear-elite-platform

The prototype should therefore keep display, sensors and Agent OS services modular enough to move onto a wearable SoC later.

## 4. Always-on cellular / notification prototype

### Nordic nRF9161

DigiKey observed price: **$32.93** for the SiP; development kit about **$158.86**.

https://www.digikey.com/en/products/detail/nordic-semiconductor-asa/NRF9161-LACA-R/22107874
https://www.digikey.com/en/product-highlight/n/nordic-semi/nrf9161-development-kit

It combines LTE-M/NB-IoT, GNSS, Cortex-M33, 1 MB flash and 256 KB RAM.

**Use it to prototype the always-on plane**, not as the only final modem. LTE-M/NB-IoT is excellent for sparse messaging and notification experiments but not a substitute for the rich-data path expected from 5G RedCap.

Early rich networking can remain Wi-Fi/BLE tethered.

## 5. Battery

### Cheap sanity-check cell

Adafruit 2500 mAh 3.7 V LiPo:
- **$14.95**;
- 50 × 60 × 7.3 mm;
- 50 g.

https://www.adafruit.com/product/328

This cell proves why a single flat 2500 mAh brick is wrong for the final cuff: it is too large and heavy in one place. It is still useful on the bench.

### Final-shape research: Grepow curved cells

Grepow lists off-the-shelf and custom curved pouch cells for wearables. Current catalogue examples extend up to **1660 mAh** in a curved cell; custom dimensions are offered over roughly 0.5–11 mm thickness, 5.6–100 mm width and 11–100 mm length, with inner arc radius ≥8 mm.

https://www.grepow.com/shaped-battery/curved-battery.htm

This strongly supports the two-wing architecture.

**Prototype recommendation:** start with two ordinary flat ~1000–1200 mAh cells in separate printed wing cavities. After geometry is stable, send the CAD envelope to Grepow or another certified custom-cell supplier.

Do not bend a normal flat LiPo to make it fit.

## 6. Ring P0 BOM

| Part | Qty | Current price / estimate | Purpose |
|---|---:|---:|---|
| Seeed XIAO nRF52840 Sense | 1 | **$15.99** | BLE + onboard IMU |
| 15–30 mAh LiPo | 1 | **$4–10 est.** | Ring power |
| Copper tape / flex electrodes | — | **$2–8 est.** | Capacitive slide/rub surface |
| Force/strain element | 1–2 | **$5–15 est.** | Squeeze detection |
| Tiny charger / protection | 1 | **$4–10 est.** | Charging |
| PETG/resin shell allocation | — | **$2–5 est.** | Oversized first ring |
| Optional UWB dev module | 1 | **$59.37** | Spatial ranging experiments |

XIAO source:
https://www.seeedstudio.com/Seeed-XIAO-BLE-Sense-nRF52840-p-5253.html

Qorvo DWM3001C UWB module:
https://store.qorvo.com/products/detail/dwm3001c-qorvo/692453/

The DWM3001C is 27 × 19.13 × 3.2 mm, so it belongs on the wrist/bench in P0, **not inside the ring**.

For a custom ring PCB, Qorvo's QM35825 UWB SoC is much smaller:
https://www.qorvo.com/products/p/QM35825

## 7. sEMG / Telekinesis lab BOM

### MyoWare 2.0

Observed price **$43.50**, electrodes sold separately.

https://www.adafruit.com/product/6423

This module is far too large to integrate into the final cuff, but it is ideal for answering the first question: which wrist/forearm placements separate pinch, tap, squeeze, finger chords and attempted micro-movements?

Once the signal set is understood, move to a custom multi-channel analog front end and dry cuff electrodes.

## 8. Optional wrist proximity / hand sensor

Pololu VL53L8CX carrier:
- **$24.95**;
- 8 × 8 zones;
- up to 4 m rated range;
- 65° FoV;
- ~100 mA typical while actively ranging.

https://www.pololu.com/product/3419

This is useful for experiments with a hand moving directly in front of the cuff, but it is too power-hungry for continuous operation. Glasses vision + ring IMU is the stronger spatial solution.

## 9. Camera prototype BOM

### Best first camera: Raspberry Pi Camera Module 3

Official:
- **from $25**;
- Sony IMX708;
- 11.9 MP;
- autofocus;
- HDR;
- 25 × 24 × 11.5 mm.

https://www.raspberrypi.com/products/camera-module-3/

Even better for a custom camera tile, Raspberry Pi now sells the **bare Camera Module 3 sensor assemblies from $15**, specifically for smaller embedded integrations:
https://www.raspberrypi.com/news/available-now-from-15-raspberry-pi-camera-module-3-sensor-assemblies/

Use the full module first; move to the sensor assembly only after the workflow works.

## 10. P1 complete budget

A realistic **functional** prototype, excluding custom PCB fabrication and shipping:

| Group | Low | High |
|---|---:|---:|
| Display + controller uncertainty | $80 | $300 |
| Wrist MCU / Linux compute | $16 | $90 |
| Battery + power | $40 | $100 |
| Mechanical / connectors / haptics | $50 | $120 |
| Camera | $25 | $50 |
| Ring | $35 | $70 |
| One MyoWare lab channel | $49 | $60 |
| Optional UWB | $0 | $60 |
| Misc. debug/FPC/adapters | $40 | $120 |
| **Approx. total** | **$335** | **$970** |

The wide range is deliberate: the display/controller and custom mechanical interconnects are the uncertain parts.

A useful first purchase order should stay near the lower half by keeping the main compute off-wrist until the mechanical concept is comfortable.

## 11. What I would buy first

1. **1–2 × Freetech 4.01" flexible AMOLED samples** with touch and whatever evaluation/bridge board the seller can provide.
2. **2 × XIAO nRF52840 Sense** — one wrist, one ring/spare.
3. **1 × MyoWare 2.0 + electrodes**.
4. **2 × 1000–1200 mAh protected LiPo** + one ~150 mAh thin cell.
5. Charger/protection, haptic, magnets, pogo pins and FPCs.
6. **Raspberry Pi Zero 2 W** and **Camera Module 3** for the functional/camera build.
7. Skip UWB until pointing with glasses/ring IMUs is ambiguous enough to justify it.

## 12. Supplier questions for the OLED vendor

Before ordering, ask for:
- exact active-area dimensions;
- flex-tail drawing;
- panel + touch thickness;
- bending radius and permitted bend region;
- MIPI DSI lane count / voltage;
- initialization command sequence;
- RM69330 or exact driver IC;
- touch-controller part number;
- evaluation board availability;
- Linux/Android reference driver;
- minimum refresh and partial-refresh support;
- idle/self-refresh current;
- maximum brightness;
- whether the flex can exit toward a short edge;
- sample lead time for 1, 2 and 10 pieces.

Without the init sequence and electrical drawing, a cheap raw OLED can become an expensive black rectangle.

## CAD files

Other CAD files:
renders/agent-phone-concept.blend

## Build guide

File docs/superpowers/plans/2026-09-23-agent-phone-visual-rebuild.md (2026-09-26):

# AGENT-PHONE Visual Rebuild Implementation Plan

> For agentic workers: use superpowers:executing-plans task-by-task.

**Goal:** Replace the misleading concept renders with a measured, mechanically coherent, visually credible wrist-computer gallery and a real visual moodboard.

**Architecture:** Keep industrial-design dimensions and scenario requirements in a plain-Python geometry module used by both tests and Blender. Generate UI textures separately, then build/render scenes from parameterized Blender helpers. Document human/photo asset licensing beside the render pipeline.

**Tech Stack:** Python 3, unittest, Pillow, Blender 5.1 Python (bpy), Markdown, Git/GitHub.

**Spec:** docs/superpowers/specs/2026-09-23-agent-phone-visual-rebuild-design.md

## Global Constraints
- Display outer target: 94 × 45 mm; active area about 91 × 42 mm.
- Long display axis runs across the wrist; short axis follows the forearm/strap direction.
- Main device uses an open cuff; no rigid underside battery/clasp.
- Edge-to-edge glass with approximately 0.7–1.5 mm visible structural border.
- Hinge/carrier is visually recessed; no large central exposed barrel.
- All product UI examples appear on the worn device.
- Existing incorrect public renders are replaced only after full-resolution manual inspection.

## Review Focus
1. Thin wrist must not intersect cuff plates or lose the underside gap.
2. At 55° tilt the display must clear the cuff/base and remain connected.
3. Watch Ultra reference remains 49 × 44 mm and is not independently scaled.
4. Chat retains a real left chat list and right conversation after texture mapping.
5. Missing human asset must fail clearly rather than silently restoring the rejected cylinder arm.

---

### Task 1: Canonical naming, links, and gallery copy
Files: README.md, renders/README.md, docs/references.md, tests/test_repo_copy.py
Produces: repository-copy invariants used by later documentation.
- [ ] Write failing tests requiring AGENT-PHONE, Concept renders, Agent OS/Sapio State URLs, ring/camera links, and forbidding the public heading Blender renders.
- [ ] Run: python3 -m unittest tests.test_repo_copy -v. Expected: FAIL.
- [ ] Update copy and first-mention cross-links.
- [ ] Re-run. Expected: PASS.
- [ ] Commit: docs: align AGENT-PHONE naming and cross-links

### Task 2: Measured geometry contract
Files: blender/design_geometry.py, tests/test_design_geometry.py, SPEC.md
Produces: DISPLAY_OUTER_MM, DISPLAY_ACTIVE_MM, WATCH_ULTRA_MM, WRIST_MODEL_MM, CUFF_GAP_MM, TILT_ANGLES_DEG, validate_geometry().
- [ ] Write failing tests: outer=(94,45,6.2), active=(91,42), watch=(49,44,14.4), long axis=across_wrist, cuff gap>=28, bezel<=1.5, tilt includes 0/30/55.
- [ ] Run: python3 -m unittest tests.test_design_geometry -v. Expected: FAIL because module is absent.
- [ ] Implement constants and validator; update SPEC orientation/dimensions.
- [ ] Re-run. Expected: PASS.
- [ ] Commit: design: lock measured AGENT-PHONE geometry

### Task 3: Wide-display UI system
Files: blender/generate_ui.py, tests/test_ui_generator.py, blender/ui/*.png
Produces textures: home, chat, marketplace, split, remote, blind-input, research, handoff, navigation, camera.
- [ ] Write failing tests for required texture set, 1400×660 size, chat left/right pane marker pixels, and >92% near-black blind-input texture.
- [ ] Run tests. Expected: FAIL.
- [ ] Redesign UI generator for realistic density and required states.
- [ ] Generate textures and re-run. Expected: PASS.
- [ ] Commit: ui: redesign wrist interfaces for wide display

### Task 4: Rebuild Blender product geometry
Files: blender/screen_concept.py, blender/scene_builder.py, blender/validate_scene.py, tests/test_scene_manifest.py
Consumes geometry constants and UI texture names; produces mechanical/lifestyle scene manifest and renders.
- [ ] Write failing manifest tests requiring comparison, closed, 30°, 55°, underside, exploded, detached, and lifestyle scene names; require screen_long_axis=across_wrist, cuff=open, watch_reference=true on comparison.
- [ ] Run tests. Expected: FAIL.
- [ ] Implement elliptical wrist coordinate system, continuous curved cuff battery plates with open underside, thin base, across-wrist display, edge-to-edge glass, recessed pivots/carrier, detachable module, and two 49×44 mm Watch Ultra references.
- [ ] Add Blender-side validation of object dimensions, cuff gap, and display/base clearance at 0/30/55°; emit JSON report and nonzero exit on violation.
- [ ] Run headless validation with Blender. Expected: PASS.
- [ ] Commit: render: rebuild measured open-cuff product geometry

### Task 5: Photorealistic hand/wrist asset path
Files: assets/human/README.md, blender/human_asset.py, tests/test_human_asset.py
Produces load_human_wrist(scene, profile) for average and slim profiles.
- [ ] Write failing metadata/loader tests: source URL, license, redistribution decision, expected local asset; missing asset raises clear exception.
- [ ] Source MakeHuman CC0 output/core asset, a licensed BlenderKit asset, or a licensed real-photo plate.
- [ ] Implement loader/profile transforms and re-run tests.
- [ ] Render one human-scale proof image and inspect it manually.
- [ ] Commit: render: add licensed realistic wrist asset pipeline

### Task 6: Visual moodboard
Files: docs/moodboard.md, docs/references.md, tests/test_moodboard.py
- [ ] Write failing test requiring film/game, wearables, cuffs/tilts, flexible displays, rings/spatial, glasses, camera; Novate URL; KEEP/AVOID/WHY; >=12 cards and >=8 visual preview URLs.
- [ ] Run. Expected: FAIL.
- [ ] Research and author board. Include Novate, Fallout, Star Citizen, Mass Effect, Nubia Alpha, Meta Neural Band/Ray-Ban Display, Apple Vision Pro, Behance/Pinterest tilting/flexible concepts, ring/spatial and detachable-camera references.
- [ ] Do not redistribute copyrighted images; use externally hosted previews/links with attribution.
- [ ] Re-run. Expected: PASS.
- [ ] Commit: docs: add visual reference moodboard

### Task 7: Scenario render set, manual QA, gallery
Files: blender/screen_concept.py, renders/README.md, renders/*.png, renders/agent-phone-concept.blend, renders/QA.md
- [ ] Render low-sample previews for required mechanical/lifestyle scenes.
- [ ] Inspect every preview manually and record pass/fail/defects in renders/QA.md.
- [ ] Fix failed scenes, re-render, re-inspect.
- [ ] Render final set and inspect full resolution for anatomy/perspective, clipping, floating plates, orientation, scale, materials, UI readability, hinge and bezel.
- [ ] Update public Concept renders gallery.
- [ ] Run full verification: unittest discover; py_compile blender/*.py; Blender validation; git diff --check.
- [ ] Commit: render: publish corrected AGENT-PHONE concept gallery

### Task 8: Review and PR
- [ ] Run final full-branch review against plan/spec.
- [ ] Fix Important/Critical findings with tests/verification.
- [ ] Push branch and open PR referencing issue #1.
- [ ] Merge only after gates pass; mark ticket shipped and complete acceptance flow.

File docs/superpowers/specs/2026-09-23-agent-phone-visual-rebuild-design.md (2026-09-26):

# AGENT-PHONE Visual Rebuild Design

Status: implementation-ready design derived from the user's reviewed handoff and render critique.

## Outcome

The repository must show a believable wrist computer rather than the current oversized slab. The new visual baseline is an open-cuff device whose display is roughly the footprint of two Apple Watch Ultra faces joined into one uninterrupted landscape screen.

The final imagery has two jobs:
- prove industrial-design proportions and mechanics;
- show believable day-to-day use directly on a human wrist.

The public repository should never require a reader to know or care that Blender produced the images. The gallery heading is **Concept renders**.

## Geometry baseline

The display module is approximately 94 × 45 mm outer size, with an active area around 91 × 42 mm. This is intentionally close to two 49 × 44 mm Apple Watch Ultra cases joined along their 49 mm direction, not a phone-width slab.

The long axis of the module runs **across the wrist**. The short axis follows the forearm/strap direction. A technical comparison render places **two** Apple Watch Ultra-sized reference blocks side by side with the device and labels the dimensions.

The screen is a single continuous surface. There is no visual split into two watch faces.
## Cuff and batteries

The base device is an open bracelet/cuff, not a watch strap with a buckle.

Two curved rigid/semi-rigid battery plates descend around the left and right sides of the wrist and stop before the underside desk-contact zone. They are physically continuous with the central base and visually read as part of one object.

The plates are asymmetrical only where wrist anatomy requires it. They must never appear as floating bars detached from the product.

The underside of the wrist remains free of a rigid battery brick or clasp so the hand can rest on a table, laptop palm rest, or keyboard edge.

A later Dive variant may add a positive clasp; the main render set shows the open cuff.

## Display and bezel

The cover glass is edge-to-edge and visually dominant. Structural metal/polymer sits underneath it rather than forming a thick picture-frame bezel.

Target visible border is approximately 0.7–1.0 mm at the left/right edges and 1.0–1.5 mm at the short ends, subject to the concept model.

The display is emissive OLED/LTPO-like: black UI areas should visually disappear into the glass.
## Tilt and detach mechanism

The screen tilts toward the user's eyes while the forearm rests naturally.

The hinge is not a large exposed barrel. The mechanism uses two short recessed pivots or a thin flexure/carrier hidden below the display edge. Closed, it should read as a thin seam.

Required mechanical states:
- closed;
- about 25–30°;
- about 50–55°;
- detached display/compute module;
- exploded carrier showing magnets/latch, power/data contacts, and the small reserve battery.

The detachable module is the compute/display unit. Its reserve cell is for a short standalone interaction, not primary endurance. The main battery mass remains in the cuff plates.

## Human model and realism

The current cylinder-and-sphere arm is rejected.

Hero and usage images must use either:
- a licensed photorealistic 3D hand/forearm asset; or
- a real licensed photograph used as a Blender compositing/background plate with correctly matched perspective and shadows.

The asset source and license must be documented in the repository. MakeHuman core assets/output are acceptable because the project documents them as CC0; BlenderKit assets are acceptable only if their individual license is recorded.

At least one thin/small wrist and one average wrist should be represented across the gallery so scale is not hidden by one body type.
## UI baseline

All product UI examples appear on the worn device, not as isolated flat mockups.

Home/status view:
- compact time;
- next calendar event;
- delivery ETA/status;
- long-running AI/deep-research progress;
- only a small number of high-value states.

Chat view uses the wide screen properly:
- left column: compact chat list with avatars, names, unread/activity state;
- right pane: current conversation with several short messages;
- bottom/right input-state indicator rather than a giant empty canvas.

Other required UI states:
- marketplace product + buy action;
- split chat + photos;
- TV / AC / lighting controls;
- blind/screen-off composition with only a tiny input indicator;
- media/display handoff;
- AI research result/progress;
- calendar/navigation;
- camera viewfinder/remote shutter context.

Typography must remain readable at realistic wrist size without giant headings.
## Scenario render set

Mechanical / scale:
1. orthographic top comparison with Apple Watch Ultra reference;
2. orthographic side closed;
3. side at 30°;
4. side at 55°;
5. open-cuff underside view;
6. exploded hinge/detach mechanism;
7. detached module in hand.

Lifestyle / product:
8. home/status while seated;
9. chat list + thread;
10. marketplace purchase;
11. split chat + photos;
12. smart-home remote;
13. blind composition with screen almost off;
14. media handoff to TV;
15. ring pointing/selecting a room device;
16. glasses companion / gaze + ring;
17. detachable camera tile used as camera while wrist/glasses act as viewfinder;
18. desk/laptop scenario proving the underside remains unobstructed;
19. outdoors quick navigation;
20. Dive variant concept.

The gallery may contain more renders, but these form the acceptance baseline.

## Moodboard

Create a real visual moodboard, not only a prose reference list.

Each reference entry contains:
- visual thumbnail or externally hosted image preview;
- source link;
- category;
- KEEP;
- AVOID;
- WHY.

Categories include film/game wrist computers, real wearables, open cuffs, tilting displays, flexible OLED concepts, landscape wrist UI, rings/spatial control, glasses, and detachable cameras.

The supplied Novate wrist-computer reference is included specifically for its open-bottom cuff and tilting display. Its keypad-heavy industrial form is not copied.
## Repository presentation

Canonical repository name: **AGENT-PHONE**.

README first mentions should link to:
- Agent OS;
- Telekinesis research;
- Agent Ring/spatial input;
- Agent Glasses concepts where described;
- Agent Camera strategy;
- Passport / Sapio State.

The public gallery uses the heading **Concept renders**. Blender implementation details live only in the render-pipeline documentation.

Existing incorrect images may be replaced in-place only after the new files have been manually inspected.

## Verification

Automated checks cover:
- dimensional constants;
- display/forearm orientation;
- bezel ratio;
- open-cuff clearance;
- required scenario names;
- required UI texture dimensions;
- no object-level bounding-box intersections between display and cuff in closed/tilted states beyond intended hinge/contact regions.

Blender renders are then inspected manually at full resolution for:
- human anatomy/perspective;
- clipping/intersections;
- floating parts;
- orientation;
- scale;
- material/texture breakage;
- UI readability;
- hinge visibility;
- bezel thickness.

A render that fails visual review is not committed merely because the script completed.

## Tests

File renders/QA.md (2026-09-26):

# Render QA

Reviewed at final resolution before merge. The user explicitly accepted the new render direction; the old oversized/rotated baseline is no longer used by the public gallery.

## Mechanical checks

- [x] Scale comparison uses AGENT-PHONE 94 × 45 mm and two Watch Ultra-sized 49 × 44 mm references.
- [x] Long display axis is across the wrist.
- [x] Closed / 30° / 55° tilt states keep the hinge recessed.
- [x] Open cuff leaves the underside of the wrist free of a rigid battery/clasp block.
- [x] Curved battery plates are physically continuous with the cuff rather than floating bars.
- [x] Detachable module and exploded carrier are readable as separate mechanical layers.
- [x] Edge-to-edge glass dominates visually; structural rim stays subordinate.

## Lifestyle checks

- [x] Home/status, chat, marketplace, split, smart-home and blind-input UIs are rendered on-wrist.
- [x] Chat uses left chat list + right conversation pane.
- [x] Ring, glasses/private-audio, camera tile, TV handoff and desk-clearance contexts are visible.
- [x] External endurance battery is shown as an optional pack with a flat power ribbon; underarm/lower-back placement remains a body-worn packaging study, not a fixed production claim.
- [x] Car HUD is shown as a sparse navigation handoff target; ordinary notifications are intentionally absent while driving.
- [x] Dive concept uses the secure-clasp direction without changing the base open-cuff architecture.
- [x] New lifestyle renders use the licensed MakeHuman CC0 human asset pipeline, not the rejected cylinder/sphere proxy.

## Rejection criteria used

A render is rejected if it shows the old 90° orientation, an oversized phone-like slab, floating cuff batteries, obvious mesh clipping, a dominant exposed hinge, a thick picture-frame bezel, or a single-pane chat UI that wastes the wide display.

The technical and lifestyle contact sheets are convenience overviews; individual PNG files remain the source for full-resolution inspection.

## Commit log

2026-09-23 Initial AGENT hardware concept and research
    [screen-concept.blend]
2026-09-26 Rebuild AGENT-PHONE visual concept and critical scenarios (#3)
    * docs: align AGENT-PHONE naming and cross-links
    * design: lock measured AGENT-PHONE geometry
    * ui: redesign wrist interfaces for wide display
    * render: rebuild measured open-cuff product geometry
    * fix: restore across-wrist display orientation
    * render: add licensed realistic wrist asset pipeline
    * docs: add visual reference moodboard
    * render: publish AGENT-PHONE scenarios and critical use cases
    [agent-phone-concept.blend, screen-concept.blend]
